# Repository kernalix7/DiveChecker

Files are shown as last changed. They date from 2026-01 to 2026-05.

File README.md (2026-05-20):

<div align="center">

DiveChecker

### See your equalization.

<p>Real-time pressure visualization for freediving equalization training — 100Hz BMP280 sensor,<br>
USB MIDI zero latency, six-platform Flutter app, ECDSA-authenticated RP2350 firmware.<br>
Two products: <strong>DiveChecker</strong> (sensor) and <strong>DiveChecker Vent</strong> (dry-land Mouthfill trainer).</p>

<pre><code># Get the app
Android: https://play.google.com/store/apps/details?id=kr.createch.divechecker
iOS:     https://apps.apple.com/kr/app/divechecker/id6758508799
Desktop: https://github.com/kernalix7/DiveChecker/releases/latest

# Buy the device
https://smartstore.naver.com/createch/products/13224634919</code></pre>

<a href="website/assets/images/hero-product.jpg">
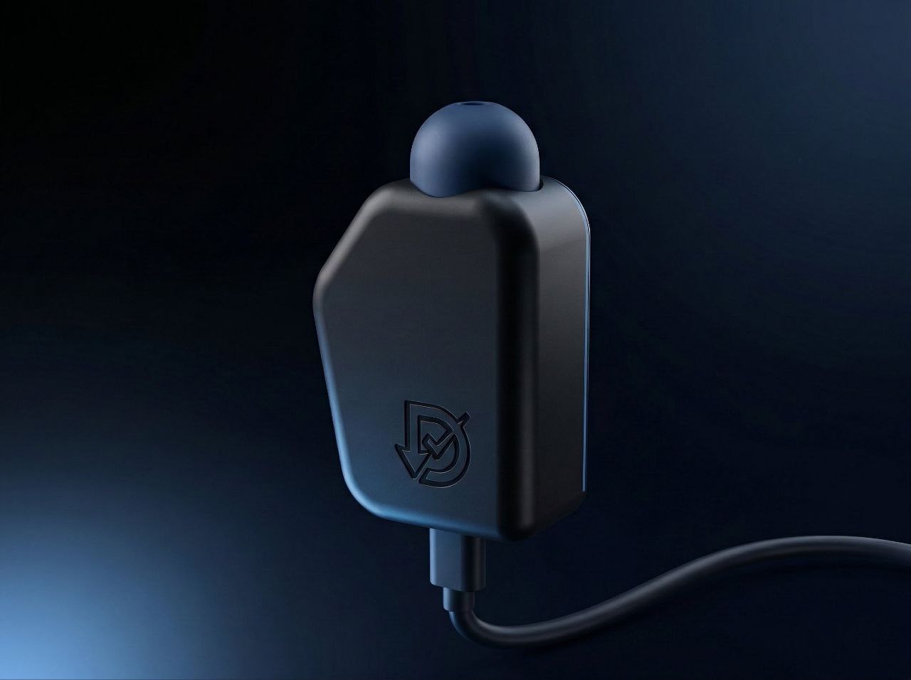
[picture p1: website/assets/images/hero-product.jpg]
DiveChecker DC-EQ01 — freediving equalization sensor
  
</a>

<sub>DiveChecker DC-EQ01 — measures nasal pressure at 100Hz, visualizes Frenzel/Valsalva/Mouthfill curves in real time.</sub>














###### Runs on








<sub>**English** &nbsp;·&nbsp; [한국어](docs/README.ko.md) &nbsp;·&nbsp; [Site](https://divechecker.createch.kr) &nbsp;·&nbsp; [Vent (Mouthfill)](https://divechecker.createch.kr/vent.html) &nbsp;·&nbsp; [Features](#-features) &nbsp;·&nbsp; [Quick Start](#-quick-start) &nbsp;·&nbsp; [Architecture](#-architecture)</sub>

</div>

---

> ### Status
> DiveChecker DC-EQ01 (sensor) is **shipping** (App v8.6.0, Firmware v6.0.0, KC-certified). DiveChecker Vent (Mouthfill dry-land trainer) is **coming soon** — sign up at the [marketing site](https://divechecker.createch.kr/vent.html). Report issues at <https://github.com/kernalix7/DiveChecker/issues>.

---

## 🎯 Overview

DiveChecker is a professional monitoring system that helps freedivers effectively practice **equalization (ear pressure equalization)** training.

Using a pressure sensor connected to a mouthpiece, it precisely measures subtle pressure changes (300-1250 hPa sensor range) when blowing or sucking through the mouth with **100Hz internal sampling + configurable output rate (4-50Hz)**, and visualizes them in real-time graphs.

### Architecture (v8.0.0)

**Smart MCU + Intelligent App**

```
[BMP280] → 100Hz → [MCU] → USB MIDI → [Flutter App]
    │                   │                       │
        └── Raw sensor      └── IIR + Averaging    └── All logic:
            data               Firmware filtering      - Display
                               Output: 4-50Hz          - Analysis
                                                       - Storage
```

| Component | Role |
|---|---|
| **MCU** | Sensor reading + IIR/Averaging filter + Configurable output rate |
| **App** | Display, analysis, storage (flexible, OTA updatable) |

### Supported Hardware

| MCU | Sensor | Status |
|-----|---|---|
| **Pico RP2350** | BMP280 | ✅ Fully supported |

### Why DiveChecker?

| Problem | DiveChecker Solution |
|---|---|
| Cannot verify if equalization is correct | Instant feedback with real-time pressure graphs |
| Difficult to measure training effectiveness | Objective evaluation with session recording + peak analysis |
| Difficult to practice consistent technique | Advanced analysis with rhythm score, fatigue index, etc. |

---

## ✨ Features

### 📊 Real-time Pressure Monitoring

<table>
<tr>
<td width="50%">

**Sensor Specs**
- **Sampling**: 100Hz internal → 4-50Hz output (configurable)
- **Firmware Filtering**: IIR x2 + Averaging
- **Latency**: ~10ms (sensor to app)
- **Sensor Range**: 300-1250 hPa (BMP280 extended)
- **Resolution**: 0.001 hPa (0.0016 hPa sensor resolution)

</td>
<td width="50%">

**Visualization**
- Real-time line chart (fl_chart)
- Pinch zoom / drag pan gestures
- 30-second sliding window
- Dynamic Y-axis auto-scaling
- Curved chart with smooth bezier
- Max/Avg pressure real-time display

</td>
</tr>
</table>

### 🔬 Advanced Peak Analysis

Detailed equalization quality analysis after measurement:

| Metric | Description |
|---|---|
| **Rhythm Score** | Peak interval consistency (CV-based) |
| **Pressure Score** | Peak intensity uniformity |
| **Technique Score** | Rise/fall time, peak width analysis |
| **Fatigue Index** | Pressure decrease trend during session |
| **Overall Grade** | S~F grade overall evaluation |

**Peak Classification**: Weak / Moderate / Strong intensity classification

### 💾 Data Management

- **SQLite / IndexedDB**: Platform-specific auto-selection (Native/Web)
- **Session Recording**: Date, time, max/avg pressure, sample rate, notes
- **Graph Notes**: Add notes at specific points (numbered markers)
- **Backup/Restore**: JSON-based data export/import
- **Cursor Indicator**: Touch position with time/pressure display

### 🌐 Multi-language Support

- 🇺🇸 English
- 🇰🇷 Korean (한국어)
- 🇯🇵 Japanese (日本語)
- 🇨🇳 Simplified Chinese (简体中文)
- 🇹🇼 Traditional Chinese (繁體中文)

### ⚙️ Calibration & Configuration

- **Atmospheric Calibration**: 3-second sample collection then baseline setting
- **Output Rate Control**: 4-50Hz via F command
- **Oversampling Adjustment**: 1x ~ 16x (MCU command)

---

## 🔐 Security & Reliability

### Device Authentication (ECDSA P-256)

| Feature | Description |
|---|---|
| **Challenge-Response** | 32-byte random nonce + ECDSA signature verification |
| **Private Key Storage** | OTP (One-Time Programmable) memory — non-extractable |
| **Constant-Time Comparison** | Timing attack prevention |
| **Memory Zeroing** | `mbedtls_platform_zeroize()` after crypto operations |

### PIN Protection

| Feature | Description |
|---|---|
| **Rate Limiting** | Exponential backoff (1s → 2s → ... → 60s max) |
| **Persistent Lockout** | PIN failure count survives reboot (Flash stored) |
| **Constant-Time PIN Verify** | No timing side-channel |

### Data Integrity

| Feature | Description |
|---|---|
| **Flash CRC32** | Settings integrity check on load |
| **Legacy Migration** | Old settings (no CRC) auto-upgraded on save |
| **Wear Leveling** | 16-slot rotation in 4KB sector |
| **3s Write Debounce** | Prevents flash wear from rapid slider changes |

### Self-Recovery Mechanisms

| Mechanism | Trigger | Recovery Action |
|---|---|---|
| **Watchdog** | 8s boot / 2s operational | Auto reboot |
| **Sensor Auto-Retry** | I2C failure | 5-second periodic retry (Core 1) |
| **App Auto-Reconnect** | USB disconnect | Exponential backoff (2/4/6s, 3 attempts) |
| **SysEx Parser Timeout** | Incomplete message | 500ms → reset to IDLE |
| **PIO Fallback** | PIO0 unavailable | Automatically use PIO1 |
| **Over-range Recovery** | Sensor saturation | Discard 30 samples after reset |

### Stability Features

| Feature | Description |
|---|---|
| **Dual-Core Isolation** | Core 0: USB/MIDI, Core 1: Sensor (100Hz) |
| **I2C Mutex Protection** | Cross-core access serialization |
| **FIFO Communication** | Lock-free inter-core message passing |
| **Saturating Counters** | Diagnostics counters never overflow |
| **Atomic Config Updates** | Output rate changes via volatile + barrier |

---

## 📱 Screens

| Screen | Description |
|---|---|
| 🏠 **Home** | Device connection, real-time pressure display, calibration |
|| 📺 **Monitor** | Real-time streaming chart with dynamic Y-axis |
|| 📈 **Measurement** | Live graph, Start/Stop/Pause, session recording |
| 📋 **History** | Session list → Graph detail → Peak analysis |
| ⚙️ **Settings** | Language, backup/restore, device settings, firmware update |

---

## 🚀 Quick Start

### Prerequisites

| Component | Version | Notes |
|---|---|---|
| Flutter SDK | 3.10.4+ | `flutter --version` |
| Pico SDK | Latest | For RP2350 firmware |
| USB Cable | - | Data transfer capable cable |

### 1. Install and Run App

```bash
git clone https://github.com/kernalix7/divechecker.git
cd divechecker/_0_DiveChecker-APP

flutter pub get
flutter gen-l10n
flutter run -d linux    # or android, windows, macos
```

### 2. Upload Firmware

```bash
# Build with Pico SDK
cd 0_Pico2-Firmware/Divechecker
mkdir build && cd build
cmake .. && make
# Copy .uf2 to Pico in BOOTSEL mode
```

### 3. Connect and Measure

1. Connect MCU to PC/Android via USB
2. App Home → **CONNECT DEVICE**
3. Select device → Connection complete
4. **Calibrate** (sensor stabilization)
5. Measurement tab → **START**

---

## 🏗️ Architecture

```
00_Divechecker/
│
├── 📱 _0_DiveChecker-APP/          # Flutter cross-platform app
│   ├── lib/
│   │   ├── main.dart               # App entry point
│   │   ├── constants/              # Theme, colors, app config
│   │   ├── core/                   # DB interface
│   │   ├── l10n/                   # Localization (EN/KO/JA/ZH/ZH_TW)
│   │   ├── models/                 # PressureData, GraphNote
│   │   ├── providers/              # State management (Provider)
│   │   │   ├── midi_provider.dart        # USB MIDI connection
│   │   │   ├── measurement_controller.dart # Measurement logic
│   │   │   └── session_repository.dart   # Session cache
│   │   ├── screens/
│   │   │   ├── home_screen.dart            # Connection & status
│   │   │   ├── monitor_screen.dart         # Real-time streaming
│   │   │   ├── measurement_screen.dart     # Real-time measurement
│   │   │   ├── history_screen.dart         # Session list
│   │   │   ├── graph_detail_page.dart      # Detailed graph + cursor
│   │   │   ├── peak_analysis_page.dart     # Peak analysis
│   │   │   ├── device_selection_screen.dart # Device selection
│   │   │   ├── device_settings_screen.dart # Device config
│   │   │   └── firmware_update_screen.dart # OTA update
│   │   ├── services/
│   │   │   ├── unified_database_service.dart  # DB integration
│   │   │   └── backup_service.dart            # Backup/restore
│   │   ├── security/
│   │   │   └── device_authenticator.dart      # ECDSA authentication
│   │   ├── utils/
│   │   │   └── peak_analyzer.dart        # Peak analysis algorithms
│   │   └── widgets/                # UI components
│   └── pubspec.yaml
│
├── 🔧 0_Pico2-Firmware/            # Pico RP2350 project
│   └── Divechecker/
│       ├── Divechecker.c           # Main firmware (dual-core, ~1800 lines)
│       ├── midi_sysex.c/h          # USB MIDI SysEx protocol
│       ├── usb_descriptors.c       # TinyUSB device descriptors
│       ├── ws2812.pio              # WS2812 LED PIO program
│       └── CMakeLists.txt          # Build config (Pico SDK 2.2.0)
│
├── 📐 0_CAD/                       # Hardware design (FreeCAD)
│
└── 📜 LICENSE                      # Apache 2.0 + CERN-OHL-S v2
```

### Communication Protocol (USB MIDI SysEx)

SysEx format: `F0 7D 01 [cmd] [data...] F7`
- Manufacturer ID: `0x7D` (educational/development)
- Device ID: `0x01` (DiveChecker)

**Device → App**

| Command | Hex | Description |
|---|-----|---|
| Pressure | 0x01 | Delta pressure (7-bit encoded int32, hPa×1000) |
| Device Info | 0x02 | Serial, name, FW version, sensor status |
| Config | 0x03 | Output rate response |
| Auth Response | 0x04 | ECDSA signature (nibble-encoded) |
| Over-range Alert | 0x06 | Sensor exceeded measurement range |
| Temperature | 0x07 | BMP280 temperature (int16×100) |
| Diagnostics | 0x08 | Uptime, error counts, I2C recovery |
| Full Config | 0x09 | All configurable parameters |
| ACK | 0x0A | Command acknowledgment (cmd + status) |
| Ping | 0x10 | Keepalive request |
| Pong | 0x11 | Keepalive response |

**App → Device**

| Command | Hex | Description |
|---|-----|---|
| Ping | 0x10 | Connection keepalive |
| Request Info | 0x20 | Request device info |
| Set Name | 0x21 | Set device name (PIN required) |
| Set Output Rate | 0x22 | Set output rate (4-50 Hz) |
| Reset Baseline | 0x23 | Reset pressure baseline |
| Get Config | 0x24 | Request full config dump |
| Set LED | 0x25 | Set LED brightness (0-100) |
| Reset Sensor | 0x26 | Manual sensor re-init |
| Factory Reset | 0x27 | Factory reset (PIN required) |
| Set Noise Floor | 0x28 | Set noise threshold (0-50) |
| Get Temperature | 0x29 | Request temperature |
| Enter Bootloader | 0x2A | Enter BOOTSEL mode (PIN required) |
| Get Diagnostics | 0x2B | Request runtime diagnostics |
| Set Oversampling | 0x2C | Set pressure oversampling (0-5) |
| Set IIR Filter | 0x2D | Set IIR filter coefficient (0-4) |
| Soft Reboot | 0x2E | Soft reboot (PIN required) |
| Auth Challenge | 0x30 | ECDSA auth (32-byte nonce) |
| Set PIN | 0x31 | Change PIN (old PIN + new PIN) |

---

## 🔧 Hardware

### Supported MCU

| MCU | Sensor | Status | Notes |
|-----|---|---|---|
| **Pico RP2350** | BMP280 | ✅ Supported | Dual-core, USB MIDI, ECDSA auth |

### Circuit Configuration

**Pico RP2350 + BMP280:**
```
Pico RP2350         BMP280 (I2C)
────────────        ────────────
3.3V         ────── VCC
GND          ────── GND
GP8 (SDA)    ────── SDA
GP9 (SCL)    ────── SCL
GP16         ────── WS2812 LED
```

### Sensor Requirements

- **Pressure Sensor**: BMP280
- **Sensitivity**: ±0.01 hPa or better recommended
- **Mouthpiece Connection**: Connect to sensor via tube

> 📌 See [0_Pico2-Firmware/Divechecker/README.md](0_Pico2-Firmware/Divechecker/README.md) for detailed setup

---

## 🔮 Roadmap

### ✅ v1.0.0 Completed
- [x] 🎯 **Real-time pressure monitoring** - 100Hz internal + configurable output
- [x] 📊 **Peak analysis** - Rhythm, pressure, technique scores
- [x] 💾 **Session management** - Record, review, notes
- [x] 🌐 **Multi-language** - English, Korean, Japanese, Chinese (Simplified/Traditional)
- [x] 🔧 **Device settings** - Output rate, oversampling control
- [x] 🔄 **Firmware update** - OTA update support
- [x] 🔐 **Authentication** - ECDSA device authentication

### 🔜 Next Goals
- [ ] ⏸️ **Monitor pause & range save** - Pause monitoring and save specific ranges
- [ ] 🫁 **Lung capacity measurement** - Max inhale/exhale volume check
- [ ] 🧘 **CO₂ table trainer** - Carbon dioxide tolerance training
- [ ] 💨 **O₂ table trainer** - Hypoxia adaptation training
- [ ] 📤 **CSV export** - External analysis tool integration
- [ ] 🌐 **Cloud sync** - Firebase-based backup
- [ ] 🎯 **Training programs** - Guided sessions (8-week course, etc.)

---

## 🤝 Contributing

Contributions are welcome!

```bash
# After forking
git clone https://github.com/YOUR_USERNAME/divechecker.git
cd divechecker/_0_DiveChecker-APP
flutter pub get
flutter run
```

See [CONTRIBUTING.md](CONTRIBUTING.md) for details.

---

## 📄 License

This project is dual-licensed:

| Component | License | Scope |
|---|---|---|
| **Software** | [Apache License 2.0](https://www.apache.org/licenses/LICENSE-2.0) | App, firmware code |
| **Hardware** | [CERN-OHL-S v2](https://ohwr.org/cern_ohl_s_v2.txt) | Circuits, CAD designs |

See the [LICENSE](LICENSE) file for details.

---

## ⭐ Star History

<a href="https://star-history.com/#kernalix7/DiveChecker&Date">
  <picture>
    <source media="(prefers-color-scheme: dark)" srcset="https://api.star-history.com/svg?repos=kernalix7/DiveChecker&type=Date&theme=dark" />
    <source media="(prefers-color-scheme: light)" srcset="https://api.star-history.com/svg?repos=kernalix7/DiveChecker&type=Date" />
    Star History Chart
  </picture>
</a>

## 💖 Sponsor

DiveChecker is built and maintained by [@kernalix7](https://github.com/kernalix7) as a one-person hardware+app+firmware+site stack. If it helps your training (or your dive shop, your students, your PB), a tip keeps the lights on for the next firmware build, the next translation pass, the next CAD revision.





Ko-fi handles international cards and PayPal; fairy.hada.io is a Korean tipping platform; the GitHub Sponsor button (repo header) wires both. Bug reports, PRs, and stars on the repo are equally appreciated and free.

See [`.github/FUNDING.yml`](.github/FUNDING.yml) for the configuration.

---

<div align="center">

**Made with ❤️ for the Freediving Community**

[⬆ Back to Top](#-divechecker)

</div>

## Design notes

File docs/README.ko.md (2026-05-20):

<div align="center">

DiveChecker

### 이퀄라이징을 눈으로 봅니다.

<p>프리다이빙 이퀄라이징 훈련용 실시간 압력 시각화 — 100Hz BMP280 센서,<br>
USB MIDI 제로 레이턴시, 6개 플랫폼 Flutter 앱, ECDSA 인증 RP2350 펌웨어.<br>
두 가지 제품: <strong>DiveChecker</strong> (센서) + <strong>DiveChecker Vent</strong> (지상 마우스필 트레이너).</p>

<pre><code># 앱 받기
Android: https://play.google.com/store/apps/details?id=kr.createch.divechecker
iOS:     https://apps.apple.com/kr/app/divechecker/id6758508799
데스크탑: https://github.com/kernalix7/DiveChecker/releases/latest

# 디바이스 구매
https://smartstore.naver.com/createch/products/13224634919</code></pre>

<a href="../website/assets/images/hero-product.jpg">
  DiveChecker DC-EQ01 — 프리다이빙 이퀄라이징 센서
</a>

<sub>DiveChecker DC-EQ01 — 코쪽 압력을 100Hz로 측정하고 프렌젤·발살바·마우스필 곡선을 실시간으로 시각화합니다.</sub>




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

###### 동작 플랫폼








<sub>[English](../README.md) &nbsp;·&nbsp; **한국어** &nbsp;·&nbsp; [사이트](https://divechecker.createch.kr) &nbsp;·&nbsp; [Vent (마우스필)](https://divechecker.createch.kr/vent.html) &nbsp;·&nbsp; [기능](#-기능) &nbsp;·&nbsp; [빠른 시작](#-빠른-시작) &nbsp;·&nbsp; [아키텍처](#-아키텍처)</sub>

</div>

---

> ### Status
> DiveChecker DC-EQ01 (센서)는 **출시 완료** (앱 v8.6.0, 펌웨어 v6.0.0, KC 인증). DiveChecker Vent (마우스필 지상 트레이너)는 **곧 출시** — [마케팅 사이트](https://divechecker.createch.kr/vent.html)에서 출시 알림 신청. 이슈는 <https://github.com/kernalix7/DiveChecker/issues>에 제보.

---

## 🎯 개요

DiveChecker는 프리다이버들이 **이퀄라이징(귀 압력 평형)** 훈련을 효과적으로 수행할 수 있도록 도와주는 전문 모니터링 시스템입니다.

마우스피스에 연결된 압력 센서를 통해 입으로 불거나 빨 때의 미세한 압력 변화(300-1250 hPa 센서 범위)를 **100Hz 내부 샘플링 + 설정 가능한 출력 속도(4-50Hz)**로 정밀하게 측정하고, 실시간 그래프로 시각화합니다.

### 아키텍처 (v8.0.0)

**스마트 MCU + 지능형 앱**

```
[BMP280] → 100Hz → [MCU] → USB MIDI → [Flutter 앱]
    │                   │                      │
        └── 원본 센서       └── IIR + 평균화       └── 모든 로직:
            데이터             펌웨어 필터링            - 표시
                               출력: 4-50Hz            - 분석
                                                       - 저장
```

| 구성요소 | 역할 |
|---|---|
| **MCU** | 센서 읽기 + IIR/평균화 필터 + 설정 가능한 출력 속도 |
| **앱** | 표시, 분석, 저장 (유연, OTA 업데이트 가능) |

### 지원 하드웨어

| MCU | 센서 | 상태 |
|-----|---|---|
| **Pico RP2350** | BMP280 | ✅ 완전 지원 |

### 왜 DiveChecker인가?

| 문제점 | DiveChecker 솔루션 |
|---|---|
| 이퀄라이징이 제대로 되는지 확인 불가 | 실시간 압력 그래프로 즉각적 피드백 |
| 훈련 효과 측정 어려움 | 세션 기록 + 피크 분석으로 객관적 평가 |
| 일관성 있는 기술 연습 어려움 | 리듬 점수, 피로도 지수 등 고급 분석 |

---

## ✨ 기능

### 📊 실시간 압력 모니터링

<table>
<tr>
<td width="50%">

**센서 스펙**
- **샘플링**: 100Hz 내부 → 4-50Hz 출력 (설정 가능)
- **펌웨어 필터링**: IIR x2 + 평균화
- **지연 시간**: ~10ms (센서 → 앱)
- **센서 범위**: 300-1250 hPa (BMP280 확장)
- **분해능**: 0.001 hPa (센서 0.0016 hPa)

</td>
<td width="50%">

**시각화**
- 실시간 라인 차트 (fl_chart)
- 핀치 줌 / 드래그 팬 제스처
- 30초 슬라이딩 윈도우
- 동적 Y축 자동 스케일링
- 부드러운 베지어 곡선 차트
- 최대/평균 압력 실시간 표시

</td>
</tr>
</table>

### 🔬 고급 피크 분석

측정 완료 후 상세한 이퀄라이징 품질 분석:

| 지표 | 설명 |
|---|---|
| **리듬 점수** | 피크 간격의 일관성 (CV 기반) |
| **압력 점수** | 피크 강도의 균일성 |
| **테크닉 점수** | 상승/하강 시간, 피크 폭 분석 |
| **피로도 지수** | 세션 중 압력 감소 추세 |
| **종합 등급** | S~F 등급으로 전체 평가 |

**피크 분류**: Weak / Moderate / Strong 강도별 분류

### 💾 데이터 관리

- **SQLite / IndexedDB**: 플랫폼별 자동 선택 (Native/Web)
- **세션 기록**: 날짜, 시간, 최대/평균 압력, 샘플 레이트, 메모
- **그래프 노트**: 특정 시점에 메모 추가 (번호 마커)
- **백업/복원**: JSON 기반 데이터 내보내기/가져오기
- **커서 인디케이터**: 터치 위치에 시간/압력 표시

### 🌐 다국어 지원

- 🇺🇸 English
- 🇰🇷 한국어
- 🇯🇵 日本語
- 🇨🇳 简体中文
- 🇹🇼 繁體中文

### ⚙️ 캘리브레이션 및 설정

- **대기압 캘리브레이션**: 3초간 샘플 수집 후 기준점 설정
- **출력 속도 조절**: F 명령으로 4-50Hz 설정
- **오버샘플링 조절**: 1x ~ 16x (MCU 명령)

---

## 🔐 보안 및 안정성

### 장치 인증 (ECDSA P-256)

| 기능 | 설명 |
|---|---|
| **챌린지-응답** | 32바이트 랜덤 논스 + ECDSA 서명 검증 |
| **개인키 저장** | OTP (One-Time Programmable) 메모리 — 추출 불가 |
| **상수 시간 비교** | 타이밍 공격 방지 |
| **메모리 제로화** | 암호화 작업 후 `mbedtls_platform_zeroize()` |

### PIN 보호

| 기능 | 설명 |
|---|---|
| **Rate Limiting** | 지수 백오프 (1초 → 2초 → ... → 최대 60초) |
| **영구 잠금** | PIN 실패 횟수 재부팅 후에도 유지 (Flash 저장) |
| **상수 시간 PIN 검증** | 타이밍 사이드채널 없음 |

### 데이터 무결성

| 기능 | 설명 |
|---|---|
| **Flash CRC32** | 로드 시 설정 무결성 검사 |
| **레거시 마이그레이션** | 이전 설정(CRC 없음) 저장 시 자동 업그레이드 |
| **마모 평준화** | 4KB 섹터 내 16슬롯 로테이션 |
| **3초 쓰기 디바운스** | 빠른 슬라이더 조작 시 Flash 마모 방지 |

### 자가복구 메커니즘

| 메커니즘 | 트리거 | 복구 동작 |
|---|---|---|
| **워치독** | 부팅 8초 / 운영 2초 | 자동 재부팅 |
| **센서 자동 재시도** | I2C 실패 | 5초마다 재시도 (Core 1) |
| **앱 자동 재연결** | USB 끊김 | 지수 백오프 (2/4/6초, 3회) |
| **SysEx 파서 타임아웃** | 불완전 메시지 | 500ms → IDLE 리셋 |
| **PIO 폴백** | PIO0 사용 불가 | 자동으로 PIO1 사용 |
| **과범위 복구** | 센서 포화 | 리셋 후 30샘플 폐기 |

### 안정성 기능

| 기능 | 설명 |
|---|---|
| **듀얼코어 분리** | Core 0: USB/MIDI, Core 1: 센서 (100Hz) |
| **I2C 뮤텍스 보호** | 크로스코어 접근 직렬화 |
| **FIFO 통신** | 락프리 코어간 메시지 전달 |
| **포화 카운터** | 진단 카운터 오버플로우 방지 |
| **원자적 설정 업데이트** | volatile + 메모리 배리어로 출력 속도 변경 |

---

## 📱 화면 구성

| 화면 | 설명 |
|---|---|
| 🏠 **홈** | 장치 연결, 실시간 압력 표시, 캘리브레이션 |
|| 📺 **모니터** | 동적 Y축 실시간 스트리밍 차트 |
|| 📈 **측정** | 실시간 그래프, 시작/정지/일시정지, 세션 저장 |
| 📋 **기록** | 세션 목록 → 상세 그래프 → 피크 분석 |
| ⚙️ **설정** | 언어, 백업/복원, 장치 설정, 펌웨어 업데이트 |

---

## 🚀 빠른 시작

### 사전 요구사항

| 구성요소 | 버전 | 비고 |
|---|---|---|
| Flutter SDK | 3.10.4+ | `flutter --version` |
| Pico SDK | 최신 | RP2350 펌웨어용 |
| USB 케이블 | - | 데이터 전송 지원 케이블 |

### 1. 앱 설치 및 실행

```bash
git clone https://github.com/kernalix7/divechecker.git
cd divechecker/_0_DiveChecker-APP

flutter pub get
flutter gen-l10n
flutter run -d linux    # 또는 android, windows, macos
```

### 2. 펌웨어 업로드

```bash
# Pico SDK로 빌드
cd 0_Pico2-Firmware/Divechecker
mkdir build && cd build
cmake .. && make
# BOOTSEL 모드에서 .uf2 파일을 Pico에 복사
```

### 3. 연결 및 측정

1. MCU를 USB로 PC/Android에 연결
2. 앱 홈 → **장치 연결**
3. 장치 선택 → 연결 완료
4. **캘리브레이션** (센서 안정화)
5. 측정 탭 → **시작**

---

## 🏗️ 아키텍처

```
00_Divechecker/
│
├── 📱 _0_DiveChecker-APP/          # Flutter 크로스플랫폼 앱
│   ├── lib/
│   │   ├── main.dart               # 앱 진입점
│   │   ├── constants/              # 테마, 색상, 앱 설정
│   │   ├── core/                   # DB 인터페이스
│   │   ├── l10n/                   # 다국어 (EN/KO/JA/ZH/ZH_TW)
│   │   ├── models/                 # PressureData, GraphNote
│   │   ├── providers/              # 상태관리 (Provider)
│   │   ├── screens/                # 화면 (장치 설정, 펌웨어 업데이트 포함)
│   │   ├── services/               # DB, 백업, 업데이트 서비스
│   │   ├── utils/                  # 피크 분석 알고리즘
│   │   └── widgets/                # UI 컴포넌트
│   └── pubspec.yaml
│
├── 🔧 0_Pico2-Firmware/            # Pico RP2350 프로젝트
│   └── Divechecker/
│       ├── Divechecker.c           # 메인 펌웨어 (듀얼코어, ~1800줄)
│       ├── midi_sysex.c/h          # USB MIDI SysEx 프로토콜
│       ├── usb_descriptors.c       # TinyUSB 디바이스 디스크립터
│       ├── ws2812.pio              # WS2812 LED PIO 프로그램
│       └── CMakeLists.txt          # 빌드 설정 (Pico SDK 2.2.0)
│
├── 📐 0_CAD/                       # 하드웨어 설계 (FreeCAD)
│
└── 📜 LICENSE                      # Apache 2.0 + CERN-OHL-S v2
```

### 통신 프로토콜 (USB MIDI SysEx)

SysEx 형식: `F0 7D 01 [cmd] [data...] F7`
- 제조사 ID: `0x7D` (교육/개발용)
- 기기 ID: `0x01` (DiveChecker)

**기기 → 앱**

| 명령 | Hex | 설명 |
|---|-----|---|
| Pressure | 0x01 | 차압 (7비트 인코딩 int32, hPa×1000) |
| Device Info | 0x02 | 시리얼, 이름, FW 버전, 센서 상태 |
| Config | 0x03 | 출력 속도 응답 |
| Auth Response | 0x04 | ECDSA 서명 (니블 인코딩) |
| Over-range Alert | 0x06 | 센서 측정 범위 초과 |
| Temperature | 0x07 | BMP280 온도 (int16×100) |
| Diagnostics | 0x08 | 가동시간, 에러 카운트, I2C 복구 |
| Full Config | 0x09 | 모든 설정 파라미터 |
| ACK | 0x0A | 명령 확인 (cmd + 상태) |
| Ping | 0x10 | 킵얼라이브 요청 |
| Pong | 0x11 | 킵얼라이브 응답 |

**앱 → 기기**

| 명령 | Hex | 설명 |
|---|-----|---|
| Ping | 0x10 | 연결 유지 |
| Request Info | 0x20 | 기기 정보 요청 |
| Set Name | 0x21 | 기기 이름 설정 (PIN 필요) |
| Set Output Rate | 0x22 | 출력 속도 설정 (4-50 Hz) |
| Reset Baseline | 0x23 | 압력 기준점 리셋 |
| Get Config | 0x24 | 전체 설정 덤프 요청 |
| Set LED | 0x25 | LED 밝기 설정 (0-100) |
| Reset Sensor | 0x26 | 수동 센서 재초기화 |
| Factory Reset | 0x27 | 공장 초기화 (PIN 필요) |
| Set Noise Floor | 0x28 | 노이즈 임계값 설정 (0-50) |
| Get Temperature | 0x29 | 온도 요청 |
| Enter Bootloader | 0x2A | BOOTSEL 모드 진입 (PIN 필요) |
| Get Diagnostics | 0x2B | 런타임 진단 요청 |
| Set Oversampling | 0x2C | 압력 오버샘플링 설정 (0-5) |
| Set IIR Filter | 0x2D | IIR 필터 계수 설정 (0-4) |
| Soft Reboot | 0x2E | 소프트 재부팅 (PIN 필요) |
| Auth Challenge | 0x30 | ECDSA 인증 (32바이트 논스) |
| Set PIN | 0x31 | PIN 변경 (기존 PIN + 새 PIN) |

---

## 🔧 하드웨어

### 지원 MCU

| MCU | 센서 | 상태 | 비고 |
|-----|---|---|---|
| **Pico RP2350** | BMP280 | ✅ 지원 | 듀얼코어, USB MIDI, ECDSA 인증 |

### 회로 구성

**Pico RP2350 + BMP280:**
```
Pico RP2350         BMP280 (I2C)
────────────        ────────────
3.3V         ────── VCC
GND          ────── GND
GP8 (SDA)    ────── SDA
GP9 (SCL)    ────── SCL
GP16         ────── WS2812 LED
```

### 센서 요구사항

- **압력 센서**: BMP280
- **감도**: ±0.01 hPa 이상 권장
- **마우스피스 연결**: 튜브로 센서와 연결

> 📌 상세 설정은 [0_Pico2-Firmware/Divechecker/README.md](../0_Pico2-Firmware/Divechecker/README.md) 참조

---

## 🔮 로드맵

### ✅ v1.0.0 완료
- [x] 🎯 **실시간 압력 모니터링** - 100Hz 내부 + 설정 가능 출력
- [x] 📊 **피크 분석** - 리듬, 압력, 테크닉 점수
- [x] 💾 **세션 관리** - 기록, 조회, 메모
- [x] 🌐 **다국어** - 영어, 한국어, 일본어, 중국어 (간체/번체)
- [x] 🔧 **장치 설정** - 출력 속도, 오버샘플링 제어
- [x] 🔄 **펌웨어 업데이트** - OTA 업데이트 지원
- [x] 🔐 **인증** - ECDSA 기기 인증

### 🔜 다음 목표
- [ ] ⏸️ **모니터 일시정지 & 범위 저장** - 모니터링 일시정지 및 특정 범위 저장
- [ ] 🫁 **폐활량 측정** - 최대 흡기/호기 용량 체크
- [ ] 🧘 **CO₂ 테이블 트레이너** - 이산화탄소 내성 훈련
- [ ] 💨 **O₂ 테이블 트레이너** - 저산소 적응 훈련
- [ ] 📤 **CSV 내보내기** - 외부 분석 도구 연동
- [ ] 🌐 **클라우드 동기화** - Firebase 기반 백업
- [ ] 🎯 **훈련 프로그램** - 가이드 세션 (8주 코스 등)

---

## 🤝 기여하기

기여를 환영합니다!

```bash
# Fork 후
git clone https://github.com/YOUR_USERNAME/divechecker.git
cd divechecker/_0_DiveChecker-APP
flutter pub get
flutter run
```

자세한 내용은 [CONTRIBUTING.md](../CONTRIBUTING.md)를 참조하세요.

---

## 📄 라이선스

이 프로젝트는 이중 라이선스로 제공됩니다:

| 구성요소 | 라이선스 | 범위 |
|---|---|---|
| **소프트웨어** | [Apache License 2.0](https://www.apache.org/licenses/LICENSE-2.0) | 앱, 펌웨어 코드 |
| **하드웨어** | [CERN-OHL-S v2](https://ohwr.org/cern_ohl_s_v2.txt) | 회로, CAD 설계 |

자세한 내용은 [LICENSE](../LICENSE) 파일을 참조하세요.

---

## ⭐ Star History

<a href="https://star-history.com/#kernalix7/DiveChecker&Date">
  <picture>
    <source media="(prefers-color-scheme: dark)" srcset="https://api.star-history.com/svg?repos=kernalix7/DiveChecker&type=Date&theme=dark" />
    <source media="(prefers-color-scheme: light)" srcset="https://api.star-history.com/svg?repos=kernalix7/DiveChecker&type=Date" />
    Star History Chart
  </picture>
</a>

## 💖 후원

DiveChecker는 [@kernalix7](https://github.com/kernalix7) 1인이 하드웨어 + 앱 + 펌웨어 + 사이트까지 통째로 만들고 유지하는 프로젝트입니다. 훈련(또는 다이브샵, 학생, PB)에 도움이 되셨다면, 작은 후원이 다음 펌웨어 빌드 / 번역 / CAD 개정의 동력이 됩니다.





Ko-fi는 해외 카드 / PayPal 결제, fairy.hada.io는 한국 후원 플랫폼, GitHub Sponsor 버튼(저장소 상단)은 두 곳을 함께 연결합니다. 버그 제보, PR, 저장소 별표도 모두 동등하게 감사하며 무료입니다.

설정은 [`.github/FUNDING.yml`](../.github/FUNDING.yml) 참조.

---

<div align="center">

**Made with ❤️ for the Freediving Community**

[⬆ 맨 위로](#-divechecker)

</div>

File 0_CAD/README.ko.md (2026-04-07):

# DiveChecker 하드웨어 설계

프리다이빙 이퀄라이징 압력 측정기의 하드웨어 설계 파일입니다.

## 파일 목록

| 파일 | 설명 |
|---|---|
| `Device_V4.FCStd` | 본체 케이스 설계 v4 (FreeCAD) |
| `BME280-5V.FCStd` | BME280 센서 모듈 케이스 (FreeCAD) |

> **참고**: `.legacy-files/` 폴더에는 이전 버전의 설계 파일들이 보관되어 있습니다.

## 소프트웨어 요구사항

- [FreeCAD](https://www.freecad.org/) 0.21+ 권장

## 출력 가이드

### 권장 설정 (FDM)

| 설정 | 값 |
|---|---|
| 레이어 높이 | 0.2mm |
| 인필 | 20% |
| 서포트 | 필요시 |
| 재질 | PLA / PETG |

## 라이선스

Copyright (C) 2025-2026 Createch (legal@createch.kr)

이 하드웨어 설계는 [CERN-OHL-S v2](https://ohwr.org/cern_ohl_s_v2.txt) 라이선스로 제공됩니다.

자세한 내용은 프로젝트 루트의 [LICENSE](../LICENSE) 파일을 참조하세요.

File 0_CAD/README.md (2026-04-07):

# DiveChecker Hardware Designs

Hardware design files for freediving equalization pressure monitor.

[🇰🇷 한국어](README.ko.md)

## File List

| File | Description |
|---|---|
| `Device_V4.FCStd` | Main case design v4 (FreeCAD) |
| `BME280-5V.FCStd` | BME280 sensor module case (FreeCAD) |

> **Note**: `.legacy-files/` folder contains previous version design files.

## Software Requirements

- [FreeCAD](https://www.freecad.org/) 0.21+ recommended

## Printing Guide

### Recommended Settings (FDM)

| Setting | Value |
|---|---|
| Layer Height | 0.2mm |
| Infill | 20% |
| Support | If needed |
| Material | PLA / PETG |

## License

Copyright (C) 2025-2026 Createch (legal@createch.kr)

These hardware designs are licensed under [CERN-OHL-S v2](https://ohwr.org/cern_ohl_s_v2.txt).

See the project root [LICENSE](../LICENSE) file for details.

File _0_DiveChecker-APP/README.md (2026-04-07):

# DiveChecker Flutter App

Cross-platform pressure monitoring app for freediving equalization training.

[🇰🇷 한국어](README.ko.md)

## Supported Platforms

| Platform | Status | Connection |
|---|---|---|
| Android | ✅ Supported | USB MIDI |
| iOS | ✅ Supported | USB MIDI |
| Linux | ✅ Supported | USB MIDI |
| Windows | ✅ Supported | USB MIDI |
| macOS | ✅ Supported | USB MIDI |
| Web | ⚠️ Limited | Web MIDI API |

## Requirements

- Flutter SDK 3.10.4+
- Dart SDK 3.10+
- DiveChecker V1 device (RP2350 Pico2)

## Getting Started

```bash
# Install dependencies
flutter pub get

# Generate localization
flutter gen-l10n

# Run
flutter run -d linux    # or android, windows, macos, ios
```

## Build

```bash
# Android APK
flutter build apk --release

# iOS
flutter build ios --release

# Linux
flutter build linux --release

# Windows
flutter build windows --release

# macOS
flutter build macos --release

# Web
flutter build web --release
```

## Project Structure

```
lib/
├── main.dart                    # App entry point
├── config/                      # Theme configuration
├── constants/                   # Constants definition
├── core/                        # DB interface
│   └── database/
├── l10n/                        # Localization (EN/KO/JA/ZH/ZH_TW)
├── models/                      # Data models
├── providers/                   # State management (Provider)
│   ├── midi_provider.dart       # USB MIDI connection
│   ├── measurement_controller.dart # Measurement logic
│   ├── session_repository.dart  # Session cache
│   ├── settings_provider.dart   # App settings
│   └── locale_provider.dart     # Language settings
├── screens/                     # Screens
│   ├── home_screen.dart         # Home (connection status)
│   ├── monitor_screen.dart      # Real-time streaming chart
│   ├── measurement_screen.dart  # Real-time measurement
│   ├── history_screen.dart      # Session history
│   ├── graph_detail_page.dart   # Detailed graph
│   ├── peak_analysis_page.dart  # Peak analysis
│   ├── settings_screen.dart     # Settings
│   ├── device_selection_screen.dart # Device selection
│   ├── device_settings_screen.dart  # Device configuration
│   └── firmware_update_screen.dart  # OTA firmware update
├── services/                    # Services
│   ├── unified_database_service.dart # DB integration
│   └── backup_service.dart      # Backup/restore
├── security/                    # Security
│   └── device_authenticator.dart # ECDSA device auth
├── utils/                       # Utilities
│   ├── chart_utils.dart         # Chart helper functions
│   └── peak_analyzer.dart       # Peak analysis algorithms
└── widgets/                     # UI components
    ├── analysis/                # Analysis widgets
    ├── common/                  # Common widgets
    ├── home/                    # Home widgets
    ├── measurement/             # Measurement widgets
    └── settings/                # Settings widgets
```

## Key Features

### 🔌 USB MIDI Communication
- Cross-platform USB MIDI support
- ECDSA device authentication
- SysEx-based data protocol
- Configurable output rate (4-50 Hz)

### 📊 Real-time Pressure Monitoring
- 100Hz internal sampling, configurable output (4-50Hz, default 8Hz)
- Real-time line chart (fl_chart) with smooth bezier curves
- Dynamic Y-axis auto-scaling on measurement & monitor charts
- Pinch zoom / drag pan gestures
- Hz-aligned grid lines
- Extended chart range up to 200 hPa

### 🔬 Peak Analysis
- Rhythm score (peak interval consistency)
- Pressure score (intensity uniformity)
- Technique score (rise/fall time)
- Fatigue index
- Overall grade (S, A, B, C, D, F)

### 💾 Data Management
- SQLite (Native) / IndexedDB (Web)
- Session recording and graph notes
- JSON backup/restore

### 🔐 Security & Reliability
- **ECDSA P-256 Authentication**: Challenge-response device verification
- **Auto-Reconnect**: Exponential backoff on USB disconnect (2/4/6s, max 3 attempts)
- **Reconnect Suppression**: Prevents auto-reconnect after intentional BOOTSEL/soft reboot
- **Non-DiveChecker Device Block**: Warning dialog for unsupported MIDI devices
- **Input Validation**: Config value range clamping
- **Timer Cleanup**: All timers cancelled on disconnect
- **Double-pop Guard**: Prevents duplicate Navigator.pop calls
- **MIDI Data Guard**: Try-catch wrapper on incoming MIDI data handler

### 🌐 Multi-language Support
- 🇺🇸 English
- 🇰🇷 Korean
- 🇯🇵 Japanese
- 🇨🇳 Simplified Chinese
- 🇹🇼 Traditional Chinese

## Testing

```bash
flutter test
```

## License

Copyright (C) 2025-2026 Createch (legal@createch.kr)

Licensed under the Apache License, Version 2.0 (the "License");
you may not use this file except in compliance with the License.
You may obtain a copy of the License at

    http://www.apache.org/licenses/LICENSE-2.0

Unless required by applicable law or agreed to in writing, software
distributed under the License is distributed on an "AS IS" BASIS,
WITHOUT WARRANTIES OR CONDITIONS OF ANY KIND, either express or implied.
See the License for the specific language governing permissions and
limitations under the License.

See the [LICENSE](../LICENSE) file in the project root for details.

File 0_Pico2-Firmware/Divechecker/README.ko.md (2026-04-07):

# DiveChecker Pico RP2350 펌웨어

Raspberry Pi Pico 2 (RP2350)용 압력 모니터링 펌웨어입니다.

[🇺🇸 English](README.md)

## 기능

- BMP280 센서로 100Hz 내부 샘플링
- 확장 측정 범위: 300-1250 hPa
- 안정적인 성능을 위한 듀얼코어 아키텍처
- 부드러운 데이터를 위한 IIR + 평균화 필터
- 연결 상태와 분리된 센서 파이프라인 (샘플링 상시 동작)
- 안전한 BOOTSEL 진입 (멀티코어 락아웃 + 인터럽트 비활성화)
- 크로스플랫폼 호환성을 위한 USB MIDI SysEx 프로토콜
- ECDSA 기기 인증
- 설정 가능한 출력 속도 (4-50 Hz)

## 요구사항

- Raspberry Pi Pico 2 (RP2350)
- BMP280 압력 센서 (I2C)
- Pico SDK

## 빌드

```bash
# Pico SDK가 없으면 클론
git clone https://github.com/raspberrypi/pico-sdk.git
cd pico-sdk
git submodule update --init

# 펌웨어 빌드
cd 0_Pico2-Firmware/Divechecker
mkdir -p build && cd build
cmake -DPICO_SDK_PATH=/path/to/pico-sdk ..
make -j4
```

출력: `Divechecker.uf2`

## 플래시

1. BOOTSEL 버튼을 누른 채로 Pico를 USB에 연결
2. `RPI-RP2` 드라이브가 나타남
3. `Divechecker.uf2`를 드라이브에 복사
4. Pico가 자동으로 재부팅

## 회로

```
Pico RP2350         BMP280 (I2C)
────────────        ────────────
3.3V         ────── VCC
GND          ────── GND
GP8 (SDA)    ────── SDA
GP9 (SCL)    ────── SCL
GP16         ────── WS2812 LED (상태 표시기)
```

## 통신 프로토콜

크로스플랫폼 호환성을 위한 USB MIDI SysEx 기반 프로토콜.

SysEx 형식: `F0 7D 01 [cmd] [data...] F7`
- 제조사 ID: `0x7D` (교육/개발용)
- 기기 ID: `0x01` (DiveChecker)

### 기기 → 앱
| 명령 | Hex | 설명 |
|---|-----|---|
| Pressure | 0x01 | 차압 (7비트 인코딩 int32, hPa×1000) |
| Device Info | 0x02 | 시리얼, 이름, FW 버전, 센서 상태 |
| Config | 0x03 | 출력 속도 응답 |
| Auth Response | 0x04 | ECDSA 서명 (니블 인코딩) |
| Over-range Alert | 0x06 | 센서 측정 범위 초과 |
| Temperature | 0x07 | BMP280 온도 (int16×100) |
| Diagnostics | 0x08 | 가동시간, 에러 카운트, I2C 복구 |
| Full Config | 0x09 | 모든 설정 가능한 파라미터 |
| ACK | 0x0A | 명령 확인 (cmd + 상태) |

### 앱 → 기기
| 명령 | Hex | 설명 |
|---|-----|---|
| Ping | 0x10 | 연결 유지 |
| Request Info | 0x20 | 기기 정보 요청 |
| Set Name | 0x21 | 기기 이름 설정 (PIN 필요) |
| Set Output Rate | 0x22 | 출력 속도 설정 (4-50 Hz) |
| Reset Baseline | 0x23 | 압력 기준점 리셋 |
| Get Config | 0x24 | 전체 설정 덤프 요청 |
| Set LED | 0x25 | LED 밝기 설정 (0-100) |
| Reset Sensor | 0x26 | 수동 센서 재초기화 |
| Factory Reset | 0x27 | 공장 초기화 (PIN 필요) |
| Set Noise Floor | 0x28 | 노이즈 임계값 설정 (0-50) |
| Get Temperature | 0x29 | 온도 요청 |
| Enter Bootloader | 0x2A | BOOTSEL 모드 진입 (PIN 필요) |
| Get Diagnostics | 0x2B | 런타임 진단 요청 |
| Set Oversampling | 0x2C | 압력 오버샘플링 설정 (0-5) |
| Set IIR Filter | 0x2D | IIR 필터 계수 설정 (0-4) |
| Soft Reboot | 0x2E | 소프트 재부팅 (PIN 필요) |
| Auth Challenge | 0x30 | ECDSA 인증 (64자 hex 논스) |
| Set PIN | 0x31 | PIN 변경 (기존 PIN + 새 PIN) |

## 키 생성

ECDSA 기기 인증용:

```bash
./generate_keys.sh
```

프로덕션 배포는 [PRODUCTION_GUIDE.md](PRODUCTION_GUIDE.md)를 참조하세요.

---

## 보안 및 안정성 기능

### 보안

| 기능 | 구현 |
|---|---|
| **ECDSA P-256 인증** | 32바이트 논스로 챌린지-응답 |
| **OTP에 개인키 저장** | 추출 불가능한 일회성 프로그래머블 저장소 |
| **상수 시간 비교** | PIN 검증으로 타이밍 공격 방지 |
| **암호 버퍼 제로화** | 사용 후 `mbedtls_platform_zeroize()` |
| **PIN Rate Limiting** | 지수 백오프 (1초 → 최대 60초) |
| **영구 잠금** | PIN 실패 횟수 재부팅 후에도 유지 |

### 안정성

| 기능 | 구현 |
|---|---|
| **워치독 타이머** | 부팅 중 8초, 운영 중 2초 |
| **센서 자동 복구** | 실패 시 5초마다 재시도 |
| **BOOTSEL 안전 종료** | 리셋 전 멀티코어 락아웃 + 인터럽트 비활성화 |
| **Flash CRC32** | 로드 시 데이터 무결성 검증 |
| **마모 평준화** | 4KB 섹터 내 16슬롯 로테이션 |
| **Flash 쓰기 디바운스** | 빠른 쓰기 방지를 위한 3초 지연 |
| **부팅 시 Flash 컴팩션** | 랩어라운드 구간의 erase 부담을 부팅 시점으로 이동 |
| **락아웃 후 I2C 유예 구간** | flash lockout 직후 일시적 NaN 샘플 무시 |
| **연속 센서 파이프라인** | 앱 연결 해제 중에도 Core 1 샘플링/필터링 지속 |
| **연결 타임아웃 여유** | keepalive 타임아웃 30초 (CONNECTION_TIMEOUT_MS)로 UI 지연 허용 |
| **SysEx 타임아웃** | 500ms 파서 리셋 (모든 상태) |
| **PIO 폴백** | PIO0 사용 불가 시 PIO1로 자동 전환 |

### 성능

| 지표 | 값 |
|---|-----|
| **내부 샘플링** | 100Hz (BMP280) |
| **측정 범위** | 300-1250 hPa (데이터시트 1100 hPa 스펙 초과 확장) |
| **출력 속도** | 4-50Hz (설정 가능) |
| **센서→앱 지연** | ~10ms |
| **Core 0** | USB MIDI + 명령 처리 |
| **Core 1** | 센서 샘플링 + IIR 필터링 |
| **코어간 통신** | 락프리 FIFO 큐 |

### 메모리 레이아웃

```
Flash (총 4MB)
├── 0x000000-0x3FEFFF: 애플리케이션 코드 + 데이터
└── 0x3FF000-0x3FFFFF: 설정 섹터 (4KB)
    └── 16 × 256바이트 슬롯 (마모 평준화)
        ├── magic (4B)
        ├── PIN (5B)
        ├── name (25B)
        ├── config (8B)
        ├── reserved (210B)
        └── CRC32 (4B)
```

## 라이선스

Copyright (C) 2025-2026 Createch (legal@createch.kr)

Apache License 2.0 (소프트웨어) 및 CERN-OHL-S v2 (하드웨어)에 따라 라이선스됩니다.

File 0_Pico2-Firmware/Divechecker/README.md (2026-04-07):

# DiveChecker Pico RP2350 Firmware

Pressure monitoring firmware for Raspberry Pi Pico 2 (RP2350).

[🇰🇷 한국어](README.ko.md)

## Features

- 100Hz internal sampling with BMP280 sensor
- Extended measurement range: 300-1250 hPa
- Dual-core architecture for stable performance
- IIR + Averaging filter for smooth data
- Connection-decoupled sensor pipeline (sampling always on)
- Safe BOOTSEL entry (multicore lockout + interrupt disable)
- USB MIDI SysEx protocol for cross-platform compatibility
- ECDSA device authentication
- Configurable output rate (4-50 Hz)

## Requirements

- Raspberry Pi Pico 2 (RP2350)
- BMP280 pressure sensor (I2C)
- Pico SDK

## Build

```bash
# Clone Pico SDK if not already installed
git clone https://github.com/raspberrypi/pico-sdk.git
cd pico-sdk
git submodule update --init

# Build firmware
cd 0_Pico2-Firmware/Divechecker
mkdir -p build && cd build
cmake -DPICO_SDK_PATH=/path/to/pico-sdk ..
make -j4
```

Output: `Divechecker.uf2`

## Flash

1. Hold BOOTSEL button while connecting Pico to USB
2. `RPI-RP2` drive will appear
3. Copy `Divechecker.uf2` to the drive
4. Pico will reboot automatically

## Circuit

```
Pico RP2350         BMP280 (I2C)
────────────        ────────────
3.3V         ────── VCC
GND          ────── GND
GP8 (SDA)    ────── SDA
GP9 (SCL)    ────── SCL
GP16         ────── WS2812 LED (status indicator)
```

## Communication Protocol

USB MIDI SysEx-based protocol for cross-platform compatibility.

SysEx format: `F0 7D 01 [cmd] [data...] F7`
- Manufacturer ID: `0x7D` (educational/development)
- Device ID: `0x01` (DiveChecker)

### Device → App
| Command | Hex | Description |
|---|-----|---|
| Pressure | 0x01 | Delta pressure (7-bit encoded int32, hPa×1000) |
| Device Info | 0x02 | Serial, name, FW version, sensor status |
| Config | 0x03 | Output rate response |
| Auth Response | 0x04 | ECDSA signature (nibble-encoded) |
| Over-range Alert | 0x06 | Sensor exceeded measurement range |
| Temperature | 0x07 | BMP280 temperature (int16×100) |
| Diagnostics | 0x08 | Uptime, error counts, I2C recovery |
| Full Config | 0x09 | All configurable parameters |
| ACK | 0x0A | Command acknowledgment (cmd + status) |

### App → Device
| Command | Hex | Description |
|---|-----|---|
| Ping | 0x10 | Connection keepalive |
| Request Info | 0x20 | Request device info |
| Set Name | 0x21 | Set device name (PIN required) |
| Set Output Rate | 0x22 | Set output rate (4-50 Hz) |
| Reset Baseline | 0x23 | Reset pressure baseline |
| Get Config | 0x24 | Request full config dump |
| Set LED | 0x25 | Set LED brightness (0-100) |
| Reset Sensor | 0x26 | Manual sensor re-init |
| Factory Reset | 0x27 | Factory reset (PIN required) |
| Set Noise Floor | 0x28 | Set noise threshold (0-50) |
| Get Temperature | 0x29 | Request temperature |
| Enter Bootloader | 0x2A | Enter BOOTSEL mode (PIN required) |
| Get Diagnostics | 0x2B | Request runtime diagnostics |
| Set Oversampling | 0x2C | Set pressure oversampling (0-5) |
| Set IIR Filter | 0x2D | Set IIR filter coefficient (0-4) |
| Soft Reboot | 0x2E | Soft reboot (PIN required) |
| Auth Challenge | 0x30 | ECDSA auth (64-char hex nonce) |
| Set PIN | 0x31 | Change PIN (old PIN + new PIN) |

## Key Generation

For ECDSA device authentication:

```bash
./generate_keys.sh
```

See [PRODUCTION_GUIDE.md](PRODUCTION_GUIDE.md) for production deployment.

---

## Security & Reliability Features

### Security

| Feature | Implementation |
|---|---|
| **ECDSA P-256 Auth** | Challenge-response with 32-byte nonce |
| **Private Key in OTP** | Non-extractable one-time programmable storage |
| **Constant-Time Compare** | PIN verification prevents timing attacks |
| **Crypto Buffer Zeroing** | `mbedtls_platform_zeroize()` after use |
| **PIN Rate Limiting** | Exponential backoff (1s → 60s max) |
| **Persistent Lockout** | PIN failure count survives reboot |

### Reliability

| Feature | Implementation |
|---|---|
| **Watchdog Timer** | 8s during boot, 2s during operation |
| **Sensor Auto-Recovery** | 5-second periodic retry on failure |
| **BOOTSEL Safe Shutdown** | Multicore lockout + interrupt disable before reset |
| **Flash CRC32** | Data integrity verification on load |
| **Wear Leveling** | 16-slot rotation in 4KB sector |
| **Flash Write Debounce** | 3-second delay prevents rapid writes |
| **Boot-Time Flash Compaction** | Erase-heavy wrap-around writes are moved to boot |
| **Lockout I2C Grace Window** | Transient NaN samples after flash lockout are ignored |
| **Continuous Sensor Pipeline** | Core 1 sampling/filtering runs even when app disconnects |
| **Connection Timeout Margin** | Keepalive timeout 30s (CONNECTION_TIMEOUT_MS) to tolerate UI jitter |
| **SysEx Timeout** | 500ms parser reset (all states) |
| **PIO Fallback** | Auto-switch to PIO1 if PIO0 unavailable |

### Performance

| Metric | Value |
|---|---|
| **Internal Sampling** | 100Hz (BMP280) |
| **Measurement Range** | 300-1250 hPa (extended beyond 1100 hPa datasheet spec) |
| **Output Rate** | 4-50Hz (configurable) |
| **Sensor-to-App Latency** | ~10ms |
| **Core 0** | USB MIDI + Command processing |
| **Core 1** | Sensor sampling + IIR filtering |
| **Inter-Core** | Lock-free FIFO queue |

### Memory Layout

```
Flash (4MB total)
├── 0x000000-0x3FEFFF: Application code + data
└── 0x3FF000-0x3FFFFF: Settings sector (4KB)
    └── 16 × 256-byte slots (wear leveling)
        ├── magic (4B)
        ├── PIN (5B)
        ├── name (25B)
        ├── config (8B)
        ├── reserved (210B)
        └── CRC32 (4B)
```

## License

Copyright (C) 2025-2026 Createch (legal@createch.kr)

Licensed under Apache License 2.0 (Software) and CERN-OHL-S v2 (Hardware).

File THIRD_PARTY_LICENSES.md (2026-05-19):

# Third-Party Licenses

DiveChecker software is licensed under [Apache License 2.0](LICENSE) and the hardware design under [CERN-OHL-S v2](https://ohwr.org/cern_ohl_s_v2.txt). This document lists the third-party components redistributed or pulled in as runtime/build dependencies, together with their upstream licenses.

## Firmware — Pico SDK + pulled libraries

### Pico SDK 2.2.0

- Upstream: <https://github.com/raspberrypi/pico-sdk>
- License: BSD-3-Clause
- Role: RP2350 (Pico 2) board support package — `pico_stdlib`, USB stack glue, multicore, hardware peripherals.

### TinyUSB

- Upstream: <https://github.com/hathach/tinyusb>
- License: MIT
- Vendored via Pico SDK
- Role: USB Device stack used to expose DiveChecker as a USB MIDI class device. See `0_Pico2-Firmware/Divechecker/usb_descriptors.c`.

### Mbed TLS

- Upstream: <https://github.com/Mbed-TLS/mbedtls>
- License: Apache-2.0
- Vendored via Pico SDK (`${PICO_SDK_PATH}/lib/mbedtls`)
- Role: ECDSA P-256 challenge/response device authentication. Subset compiled with custom `mbedtls_config.h` for footprint.

## App — Flutter pub packages

Managed via `_0_DiveChecker-APP/pubspec.yaml`. Each upstream's full license is in `pub.dev` and the `.pub-cache` lockfile.

| Package | License | Use |
|---|---|-----|
| `flutter_midi_command` ^0.5.3 | MIT | USB MIDI SysEx I/O on Android / iOS / macOS / Windows / Linux |
| `permission_handler` ^11.3.1 | MIT | Runtime permissions on mobile |
| `fl_chart` ^0.70.2 | MIT | Real-time pressure visualization |
| `sqflite` ^2.4.2 | MIT | Native SQLite |
| `sqflite_common_ffi` ^2.3.4+5 | MIT | SQLite on desktop (Linux/Windows/macOS) |
| `idb_shim` ^2.6.1+1 | BSD-3-Clause | IndexedDB shim on Web |
| `path` ^1.9.1 | BSD-3-Clause | Path manipulation |
| `path_provider` ^2.1.5 | BSD-3-Clause | Platform path discovery |
| `file_picker` ^8.1.7 | MIT | JSON backup/restore file picking |
| `provider` ^6.1.4 | MIT | State management |
| `pointycastle` (transitive) | MIT | ECDSA P-256 signature verification on the app side |
| `cupertino_icons` ^1.0.8 | MIT | iOS-style icons |

Flutter SDK itself is BSD-3-Clause (<https://github.com/flutter/flutter/blob/master/LICENSE>).

## Linux Flutter plugin override

`packages/flutter_midi_command_linux/` is a custom fork to support ALSA RawMIDI on Linux desktop. Forked from `flutter_midi_command_linux` (MIT). Modifications preserved under the same license.

## Marketing site (`website/`)

- Inter font — SIL Open Font License 1.1 (<https://github.com/rsms/inter>)
- Noto Sans KR — SIL Open Font License 1.1 (<https://fonts.google.com/noto>)
- All other assets (logo, hero renders, OG images) © 2025-2026 Createch — All rights reserved.

## Hardware (`0_CAD/`)

DiveChecker enclosure (V4–V11) is **CERN-OHL-S v2**. FreeCAD files reference the BME280 5V breakout module footprint; no proprietary symbols redistributed.

## Attribution

Build dependencies discovered automatically via the package manager (`flutter pub get` / Pico SDK install) are not listed individually here. For an exhaustive transitive list, see:

- `_0_DiveChecker-APP/pubspec.lock` (Flutter deps)
- `${PICO_SDK_PATH}/LICENSE.TXT` and the `mbedtls/`, `tinyusb/` subtrees (firmware deps)

If you find a dependency missing or mis-attributed, please open an issue at <https://github.com/kernalix7/DiveChecker/issues>.

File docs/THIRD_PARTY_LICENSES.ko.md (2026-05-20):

# 서드파티 라이선스

[English](../THIRD_PARTY_LICENSES.md) | **한국어**

DiveChecker 소프트웨어는 [Apache License 2.0](../LICENSE), 하드웨어 설계는 [CERN-OHL-S v2](https://ohwr.org/cern_ohl_s_v2.txt)로 라이선스됩니다. 이 문서는 소스 트리 내 재배포되거나 런타임/빌드 의존성으로 끌어다 쓰는 서드파티 구성요소를 업스트림 라이선스와 함께 나열합니다.

## 펌웨어 — Pico SDK + 사용 라이브러리

### Pico SDK 2.2.0

- Upstream: <https://github.com/raspberrypi/pico-sdk>
- License: BSD-3-Clause
- 역할: RP2350 (Pico 2) 보드 지원 패키지 — `pico_stdlib`, USB 스택, 멀티코어, 하드웨어 페리페럴.

### TinyUSB

- Upstream: <https://github.com/hathach/tinyusb>
- License: MIT
- 벤더링: Pico SDK 경유
- 역할: DiveChecker를 USB MIDI class device로 노출시키는 USB Device 스택. `0_Pico2-Firmware/Divechecker/usb_descriptors.c` 참조.

### Mbed TLS

- Upstream: <https://github.com/Mbed-TLS/mbedtls>
- License: Apache-2.0
- 벤더링: Pico SDK 경유 (`${PICO_SDK_PATH}/lib/mbedtls`)
- 역할: ECDSA P-256 challenge/response 디바이스 인증. 메모리 footprint를 위해 커스텀 `mbedtls_config.h`로 서브셋만 컴파일.

## 앱 — Flutter pub 패키지

`_0_DiveChecker-APP/pubspec.yaml`에서 관리. 각 업스트림 전체 라이선스는 `pub.dev` 및 `.pub-cache` lockfile에서 확인 가능.

| 패키지 | 라이선스 | 용도 |
|---|---|---|
| `flutter_midi_command` ^0.5.3 | MIT | Android / iOS / macOS / Windows / Linux에서 USB MIDI SysEx I/O |
| `permission_handler` ^11.3.1 | MIT | 모바일 런타임 권한 |
| `fl_chart` ^0.70.2 | MIT | 실시간 압력 시각화 |
| `sqflite` ^2.4.2 | MIT | 네이티브 SQLite |
| `sqflite_common_ffi` ^2.3.4+5 | MIT | 데스크탑(Linux/Windows/macOS) SQLite |
| `idb_shim` ^2.6.1+1 | BSD-3-Clause | Web IndexedDB shim |
| `path` ^1.9.1 | BSD-3-Clause | 경로 조작 |
| `path_provider` ^2.1.5 | BSD-3-Clause | 플랫폼별 경로 탐지 |
| `file_picker` ^8.1.7 | MIT | JSON 백업/복원 파일 선택 |
| `provider` ^6.1.4 | MIT | 상태 관리 |
| `pointycastle` (transitive) | MIT | 앱 측 ECDSA P-256 서명 검증 |
| `cupertino_icons` ^1.0.8 | MIT | iOS 스타일 아이콘 |

Flutter SDK 자체는 BSD-3-Clause (<https://github.com/flutter/flutter/blob/master/LICENSE>).

## Linux Flutter plugin override

`packages/flutter_midi_command_linux/`는 Linux 데스크탑 ALSA RawMIDI 지원을 위해 커스텀 fork. 원본 `flutter_midi_command_linux` (MIT)에서 fork. 동일 라이선스 유지.

## 마케팅 사이트 (`website/`)

- Inter 폰트 — SIL Open Font License 1.1 (<https://github.com/rsms/inter>)
- Noto Sans KR — SIL Open Font License 1.1 (<https://fonts.google.com/noto>)
- 그 외 자산 (로고, 히어로 렌더, OG 이미지) © 2025-2026 Createch — All rights reserved.

## 하드웨어 (`0_CAD/`)

DiveChecker 케이스 (V4–V11)는 **CERN-OHL-S v2**. FreeCAD 파일은 BME280 5V breakout 모듈 footprint를 참조하며, 독점 심볼은 재배포하지 않음.

## Attribution

패키지 매니저(`flutter pub get` / Pico SDK 설치)로 자동 발견되는 빌드 의존성은 여기에 개별 나열하지 않음. 전체 transitive 목록은 다음을 참조:

- `_0_DiveChecker-APP/pubspec.lock` (Flutter 의존성)
- `${PICO_SDK_PATH}/LICENSE.TXT` 및 `mbedtls/`, `tinyusb/` 서브트리 (펌웨어 의존성)

누락 / 잘못 표기된 의존성을 발견하시면 <https://github.com/kernalix7/DiveChecker/issues>에 이슈 등록 부탁드립니다.

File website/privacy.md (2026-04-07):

# Privacy Policy

**English** | [한국어](PRIVACY_POLICY.ko.md)

**Effective Date: March 26, 2026**

## Introduction

DiveChecker ("the App") is a freediving equalization pressure monitoring application developed by Createch ("we", "us", "our"). This Privacy Policy explains how the App handles user information.

## Data Collection

**The App does not collect, transmit, or share any personal data.**

All data generated by the App — including pressure measurement sessions, chart annotations, and user preferences — is stored **exclusively on your device** in local storage (SQLite database and SharedPreferences). No data is sent to external servers, cloud services, or third parties.

## Network Access

The App does **not** require internet access. The release build does not include the `INTERNET` permission. The App functions entirely offline.

## Hardware Communication

The App communicates with the DiveChecker hardware device via **USB MIDI** connection only. This communication occurs locally between your device and the connected hardware. No data from this communication is transmitted over any network.

## Device Authentication

The App uses ECDSA P-256 cryptographic signature verification to authenticate connected DiveChecker hardware devices. This process is performed locally on-device and does not involve any external servers.

## Third-Party Services

The App does **not** integrate with any third-party analytics, advertising, crash reporting, or tracking services. There are no third-party SDKs that collect user data.

## Data Storage and Retention

- **Measurement data**: Stored locally in SQLite database on your device
- **User preferences**: Stored locally via SharedPreferences (theme, language, notification settings, etc.)
- **Data export**: You may manually export measurement data as JSON files to your device's storage. This is entirely user-initiated and remains on your device.

You can delete all app data at any time by clearing the app's data through your device settings or by uninstalling the App.

## Children's Privacy

The App is not directed at children under the age of 13. It is a specialized tool designed for freediving training that requires dedicated hardware equipment.

## Changes to This Policy

We may update this Privacy Policy from time to time. Any changes will be reflected in this document with an updated effective date.

## Contact

If you have any questions about this Privacy Policy, please contact us:

- Email: cs-divechecker@createch.kr
- GitHub: [https://github.com/kernalix7/DiveChecker](https://github.com/kernalix7/DiveChecker)

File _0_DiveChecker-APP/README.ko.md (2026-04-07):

# DiveChecker Flutter 앱

프리다이빙 이퀄라이징 훈련을 위한 크로스플랫폼 압력 모니터링 앱입니다.

[🇺🇸 English](README.md)

## 지원 플랫폼

| 플랫폼 | 상태 | 연결 |
|---|---|---|
| Android | ✅ 지원 | USB MIDI |
| iOS | ✅ 지원 | USB MIDI |
| Linux | ✅ 지원 | USB MIDI |
| Windows | ✅ 지원 | USB MIDI |
| macOS | ✅ 지원 | USB MIDI |
| Web | ⚠️ 제한적 | Web MIDI API |

## 요구사항

- Flutter SDK 3.10.4+
- Dart SDK 3.0+
- DiveChecker V1 기기 (RP2350 Pico2)

## 시작하기

```bash
# 의존성 설치
flutter pub get

# 로컬라이제이션 생성
flutter gen-l10n

# 실행
flutter run -d linux    # 또는 android, windows, macos, ios
```

## 빌드

```bash
# Android APK
flutter build apk --release

# iOS
flutter build ios --release

# Linux
flutter build linux --release

# Windows
flutter build windows --release

# macOS
flutter build macos --release
```

## 프로젝트 구조

```
lib/
├── main.dart                    # 앱 진입점
├── config/                      # 테마 설정
├── constants/                   # 상수 정의
├── core/                        # DB 인터페이스
│   └── database/
├── l10n/                        # 다국어 지원 (EN/KO/JA/ZH/ZH_TW)
├── models/                      # 데이터 모델
├── providers/                   # 상태 관리 (Provider)
│   ├── midi_provider.dart       # USB MIDI 연결
│   ├── measurement_controller.dart # 측정 로직
│   ├── session_repository.dart  # 세션 캐시
│   ├── settings_provider.dart   # 앱 설정
│   └── locale_provider.dart     # 언어 설정
├── screens/                     # 화면
│   ├── home_screen.dart         # 홈 (연결 상태)
│   ├── monitor_screen.dart      # 실시간 스트리밍 차트
│   ├── measurement_screen.dart  # 실시간 측정
│   ├── history_screen.dart      # 세션 기록
│   ├── graph_detail_page.dart   # 상세 그래프
│   ├── peak_analysis_page.dart  # 피크 분석
│   ├── settings_screen.dart     # 설정
│   ├── device_selection_screen.dart # 장치 선택
│   ├── device_settings_screen.dart  # 장치 설정
│   └── firmware_update_screen.dart  # OTA 펌웨어 업데이트
├── services/                    # 서비스
│   ├── unified_database_service.dart # DB 통합
│   └── backup_service.dart      # 백업/복원
├── security/                    # 보안
│   └── device_authenticator.dart # ECDSA 기기 인증
├── utils/                       # 유틸리티
│   ├── chart_utils.dart         # 차트 헬퍼 함수
│   └── peak_analyzer.dart       # 피크 분석 알고리즘
└── widgets/                     # UI 컴포넌트
    ├── analysis/                # 분석 위젯
    ├── common/                  # 공통 위젯
    ├── home/                    # 홈 위젯
    ├── measurement/             # 측정 위젯
    └── settings/                # 설정 위젯
```

## 주요 기능

### 🔌 USB MIDI 통신
- 크로스플랫폼 USB MIDI 지원
- ECDSA 기기 인증
- SysEx 기반 데이터 프로토콜
- 출력 속도 설정 가능 (4-50 Hz)

### 📊 실시간 압력 모니터링
- 160Hz 내부 샘플링, 설정 가능 출력 (4-50Hz, 기본 8Hz)
- 실시간 라인 차트 (fl_chart) 부드러운 베지어 곡선
- 측정/모니터 차트 동적 Y축 자동 스케일링
- 핀치 줌 / 드래그 팬 제스처
- Hz 기준 그리드 라인
- 차트 범위 200 hPa까지 확장

### 🔬 피크 분석
- 리듬 점수 (피크 간격 일관성)
- 압력 점수 (강도 균일성)
- 테크닉 점수 (상승/하강 시간)
- 피로도 지수
- 종합 등급 (S, A, B, C, D, F)

### 💾 데이터 관리
- SQLite (Native) / IndexedDB (Web)
- 세션 기록 및 그래프 노트
- JSON 백업/복원

### 🔐 보안 및 안정성
- **ECDSA P-256 인증**: 챌린지-응답 기기 검증
- **자동 재연결**: USB 끊김 시 지수 백오프 (2/4/6초, 최대 3회)
- **재연결 억제**: BOOTSEL/소프트 재부팅 후 자동 재연결 방지
- **비-DiveChecker 기기 차단**: 지원되지 않는 MIDI 기기 경고 다이얼로그
- **입력 검증**: 설정값 범위 제한 (clamp)
- **타이머 정리**: 연결 해제 시 모든 타이머 취소
- **Double-pop 방지**: Navigator.pop 중복 호출 방지
- **MIDI 데이터 보호**: 수신 MIDI 데이터 핸들러 try-catch 래핑

### 🌐 다국어 지원
- 🇺🇸 English
- 🇰🇷 한국어
- 🇯🇵 日本語
- 🇨🇳 简体中文
- 🇹🇼 繁體中文

## 테스트

```bash
# 단위 테스트
flutter test

# 통합 테스트
flutter test integration_test/
```

## 라이선스

Copyright (C) 2025-2026 Createch (legal@createch.kr)

Apache License 2.0에 따라 라이선스가 부여됩니다.

자세한 내용은 프로젝트 루트의 [LICENSE](../LICENSE) 파일을 참조하세요.

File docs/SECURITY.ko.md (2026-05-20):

# 보안 정책

[English](../SECURITY.md) | **한국어**

## 지원 버전

| 버전 | 지원 여부 |
|---|---|
| 최신 | Yes |

DiveChecker는 활발히 개발 중이며, 보안 업데이트는 `main` 브랜치의 최신 버전에 적용됩니다.

## 취약점 제보 방법

보안 취약점은 GitHub Security Advisories를 통해 제보해 주세요:

**[취약점 제보하기](https://github.com/kernalix7/DiveChecker/security/advisories/new)**

**보안 취약점은 공개 GitHub 이슈로 제보하지 마세요.**

### 제보 시 포함할 내용

- **설명**: 취약점에 대한 명확한 설명
- **재현 단계**: 문제를 재현하기 위한 상세 단계
- **영향**: 취약점의 잠재적 영향
- **영향받는 구성요소**: 앱 / 펌웨어 / 하드웨어 / 마케팅 사이트
- **환경**:
  - OS 및 버전
  - 앱 버전 (Flutter)
  - 펌웨어 버전 (RP2350)
  - 디바이스 모델 (DC-EQ01 / Vent)
  - 연결 방식 (USB-C / Lightning 어댑터)

## 대응 일정

| 단계 | 기간 |
|---|-----|
| 접수 확인 | 48시간 이내 |
| 초기 평가 | 7일 이내 |
| 수정 | 30일 이내 |

## 범위

In-scope:

- ECDSA P-256 디바이스 인증 우회 또는 키 추출
- USB MIDI SysEx 프로토콜 인젝션 또는 버퍼 오버플로우
- 펌웨어 메모리 손상 또는 코드 실행
- Flutter 앱 데이터 유출 (세션 데이터, 디바이스 키)
- 크로스플랫폼 데이터베이스 (SQLite/IndexedDB) 인젝션
- RP2350 OTP 키 저장소 취약점
- 불안전한 펌웨어 업데이트 메커니즘
- USB 통신 가로채기 / 재전송 공격
- 마케팅 사이트 (divechecker.createch.kr): XSS, CSP 우회, 공급망 (CDN/의존성) 공격

Out of scope:

- 사용자 호스트 머신에 물리적 접근이 필요한 버그
- 소셜 엔지니어링 공격
- 서드파티 의존성의 문제 (업스트림에 제보해 주시되, 알려주시면 감사합니다)

## 보안 모범 사례

DiveChecker가 따르는 관행:

- **ECDSA P-256 디바이스 인증** — 정품 하드웨어의 암호학적 검증
- **OTP 키 저장** — 프로덕션 키는 RP2350 일회성 프로그래밍 메모리에 저장
- **펌웨어 동적 메모리 미사용** — 고정 크기 버퍼로 힙 기반 공격 방지
- **입력 검증** — 모든 SysEx 명령은 처리 전 검증
- **PIN 보호 설정** — 디바이스 설정 변경 시 PIN 인증 필요
- **네트워크 통신 없음** — 순수 USB 연결, 클라우드/인터넷 의존성 없음
- **사이트 CSP + canonical URLs** — 마케팅 사이트는 canonical href + OG/Twitter meta만 사용

## 감사의 말

책임감 있는 취약점 공개에 힘써주시는 보안 연구 커뮤니티에 감사드립니다. 유효한 보안 이슈를 제보해 주신 분은 (동의 시) 릴리스 노트에서 감사를 표합니다.

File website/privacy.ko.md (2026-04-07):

# 개인정보처리방침

[English](PRIVACY_POLICY.md) | **한국어**

**시행일: 2026년 3월 26일**

## 소개

DiveChecker("본 앱")는 크리에이테크 (Createch)("당사")가 개발한 프리다이빙 이퀄라이징 압력 모니터링 애플리케이션입니다. 본 개인정보처리방침은 앱의 정보 처리 방식을 설명합니다.

## 데이터 수집

**본 앱은 어떠한 개인정보도 수집, 전송, 공유하지 않습니다.**

앱에서 생성되는 모든 데이터 — 압력 측정 세션, 차트 메모, 사용자 설정 등 — 는 **기기의 로컬 저장소**에만 저장됩니다(SQLite 데이터베이스 및 SharedPreferences). 외부 서버, 클라우드 서비스 또는 제3자에게 데이터를 전송하지 않습니다.

## 네트워크 접근

본 앱은 인터넷 접근을 **필요로 하지 않습니다.** 릴리즈 빌드에는 `INTERNET` 권한이 포함되지 않으며, 앱은 완전히 오프라인으로 동작합니다.

## 하드웨어 통신

앱은 **USB MIDI** 연결을 통해서만 DiveChecker 하드웨어 장치와 통신합니다. 이 통신은 기기와 연결된 하드웨어 간에 로컬로 수행되며, 어떠한 네트워크를 통해서도 데이터가 전송되지 않습니다.

## 기기 인증

앱은 ECDSA P-256 암호화 서명 검증을 사용하여 연결된 DiveChecker 하드웨어 장치를 인증합니다. 이 과정은 기기 내에서 로컬로 수행되며 외부 서버를 사용하지 않습니다.

## 제3자 서비스

본 앱은 제3자 분석, 광고, 크래시 리포팅 또는 추적 서비스를 **통합하지 않습니다.** 사용자 데이터를 수집하는 제3자 SDK가 없습니다.

## 데이터 저장 및 보관

- **측정 데이터**: 기기의 SQLite 데이터베이스에 로컬 저장
- **사용자 설정**: SharedPreferences를 통해 로컬 저장 (테마, 언어, 알림 설정 등)
- **데이터 내보내기**: 측정 데이터를 JSON 파일로 기기 저장소에 수동 내보내기 가능. 이는 전적으로 사용자가 시작하는 작업이며 기기에 보관됩니다.

기기 설정에서 앱 데이터를 삭제하거나 앱을 제거하면 언제든지 모든 앱 데이터를 삭제할 수 있습니다.

## 아동 개인정보

본 앱은 13세 미만의 아동을 대상으로 하지 않습니다. 전용 하드웨어 장비가 필요한 프리다이빙 훈련용 전문 도구입니다.

## 정책 변경

본 개인정보처리방침은 수시로 업데이트될 수 있습니다. 변경 사항은 시행일 업데이트와 함께 본 문서에 반영됩니다.

## 연락처

본 개인정보처리방침에 대한 문의사항은 아래로 연락해 주시기 바랍니다:

- 이메일: cs-divechecker@createch.kr
- GitHub: [https://github.com/kernalix7/DiveChecker](https://github.com/kernalix7/DiveChecker)

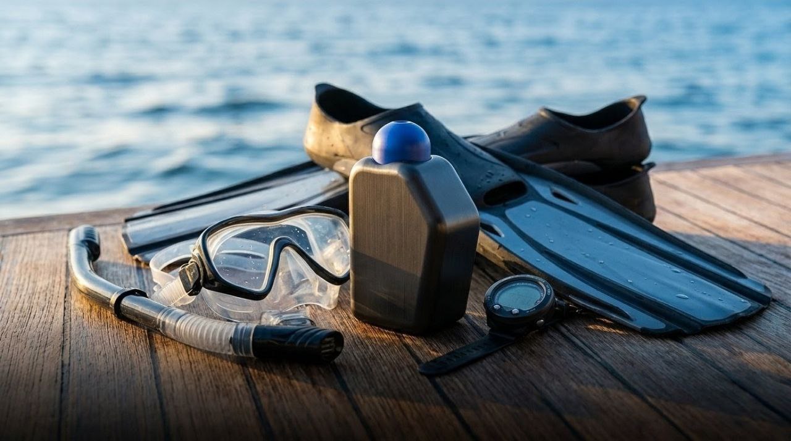
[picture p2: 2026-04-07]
website/assets/images/lifestyle.jpg

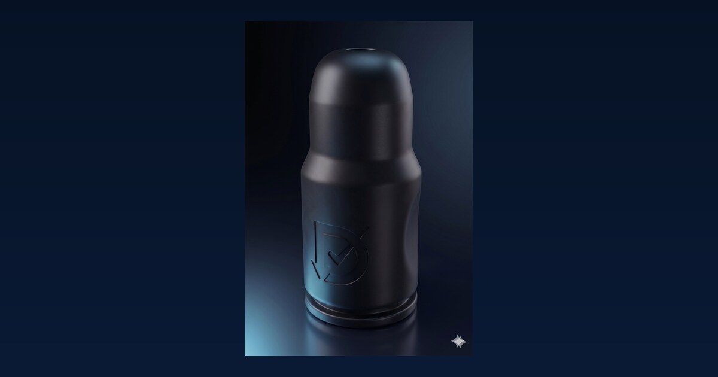
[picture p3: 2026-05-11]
website/assets/images/og-vent.jpg

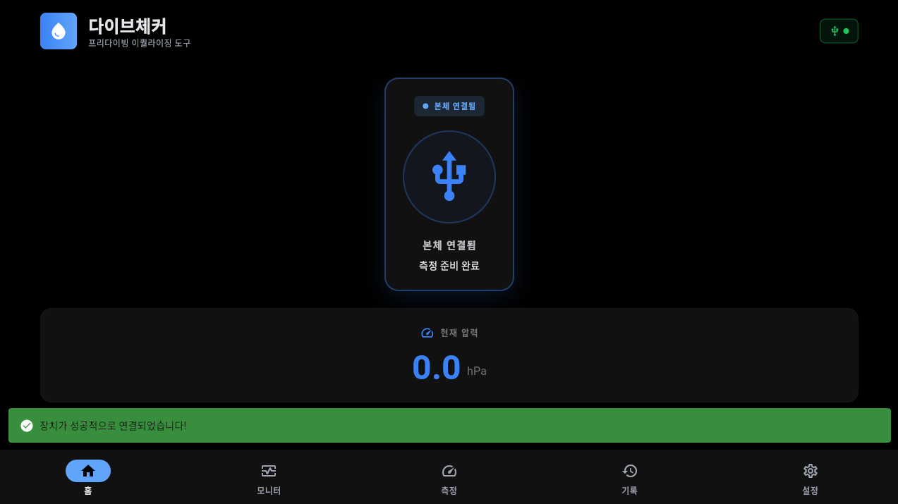
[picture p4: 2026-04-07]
website/assets/images/app-mockup.png

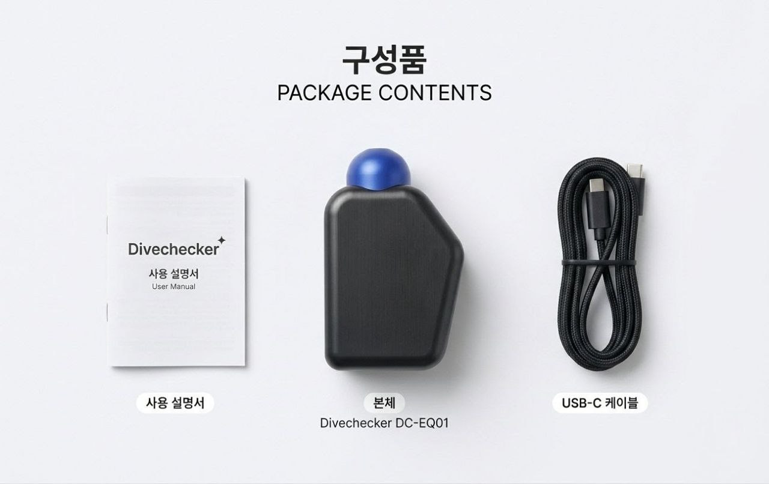
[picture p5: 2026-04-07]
website/assets/images/package-contents.jpg

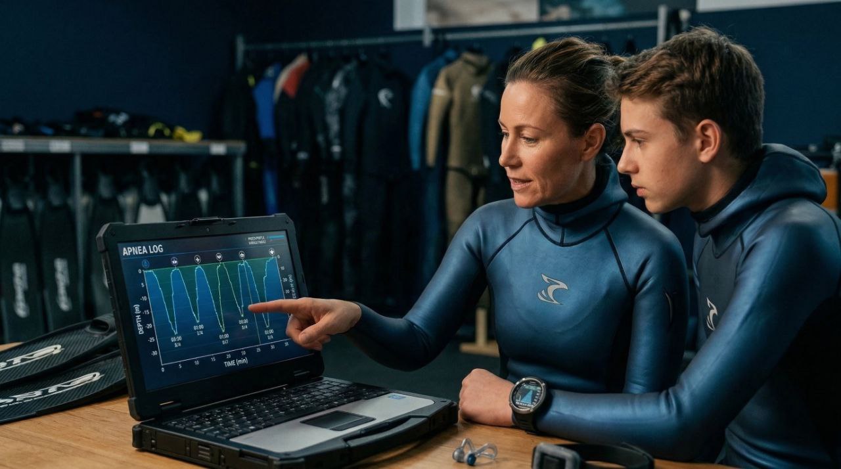
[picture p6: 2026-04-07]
website/assets/images/feature-analysis.jpg

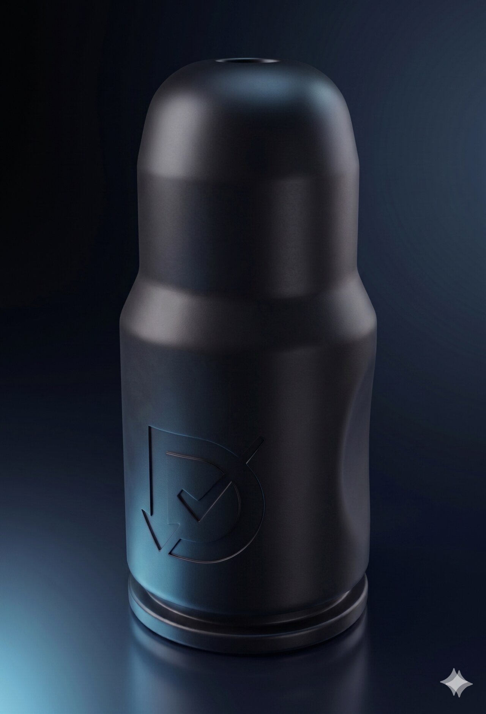
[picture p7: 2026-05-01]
website/assets/images/vent-hero.jpg

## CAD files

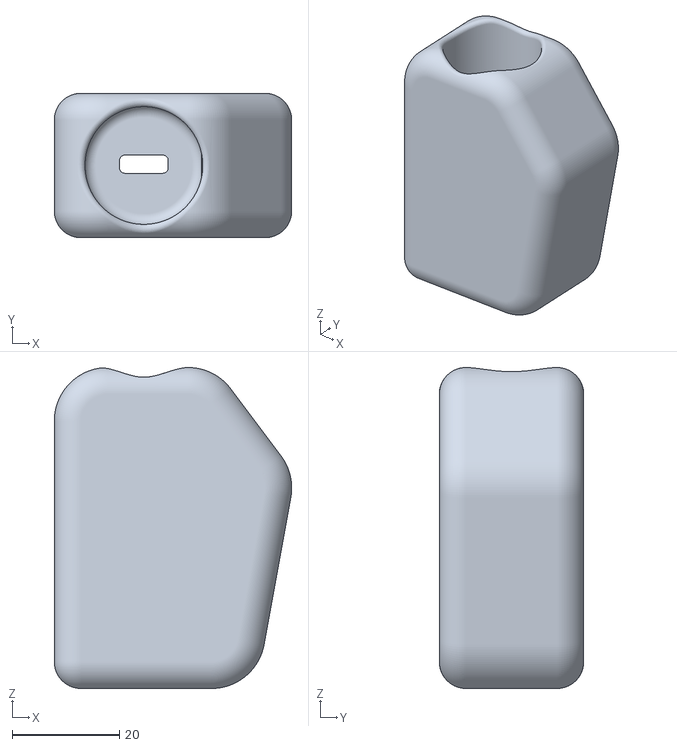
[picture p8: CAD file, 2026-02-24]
0_CAD/Device_V10-Main-body.stl
44.4 x 27.0 x 60.0

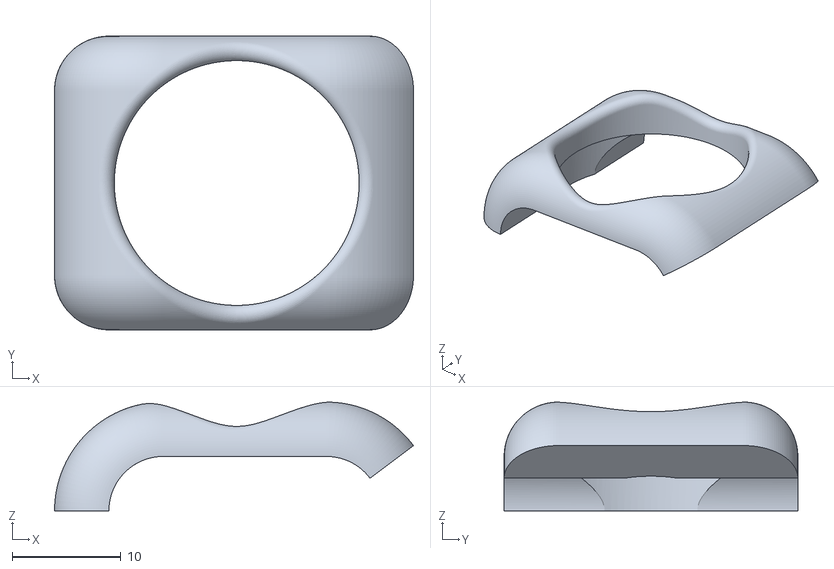
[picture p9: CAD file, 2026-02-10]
0_CAD/Device_V7-1-Main-body001.stl
33.0 x 27.0 x 9.99

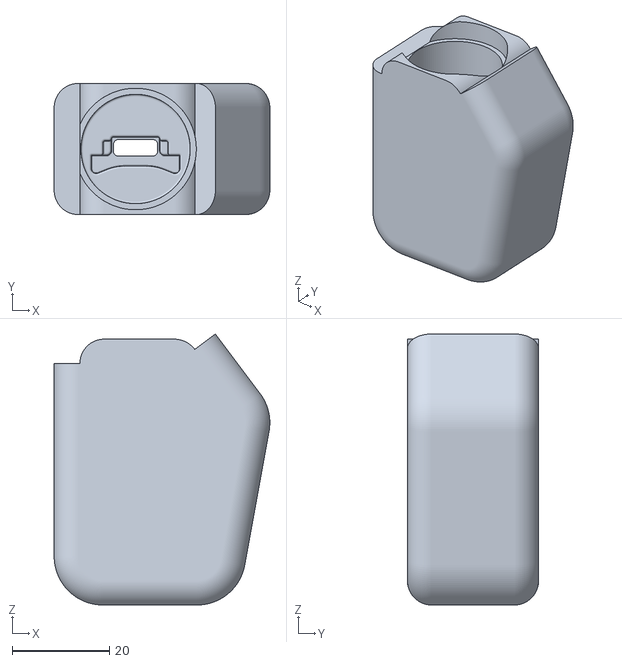
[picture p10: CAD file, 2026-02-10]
0_CAD/Device_V7-1-Main-body.stl
44.4 x 27.0 x 55.8

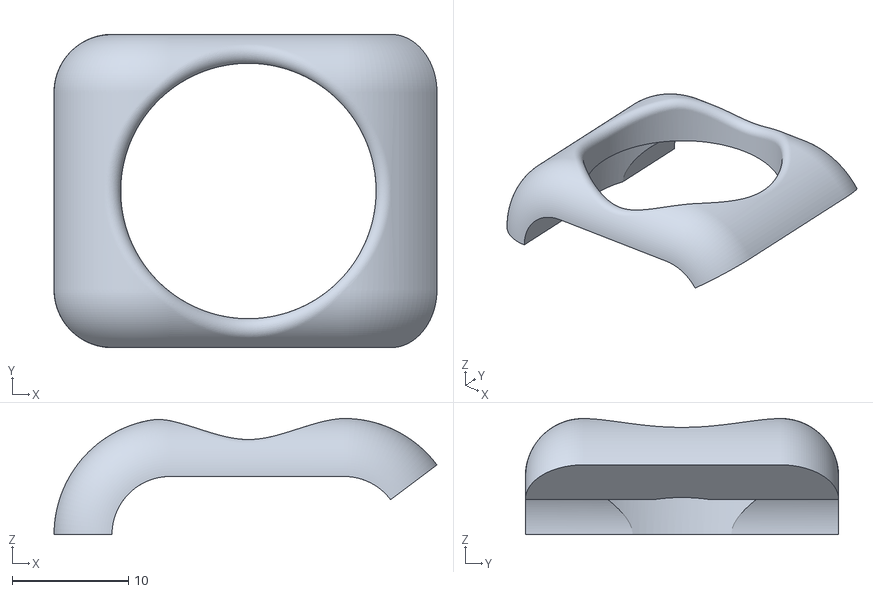
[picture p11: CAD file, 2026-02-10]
0_CAD/Device_V7-Main-body001.stl
33.0 x 27.0 x 10.00

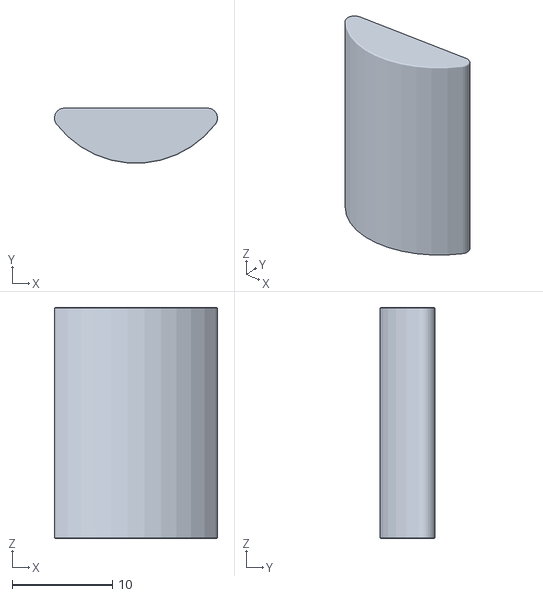
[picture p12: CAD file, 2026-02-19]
0_CAD/Device_V9-Core-sub.stl
16.2 x 5.47 x 23.0

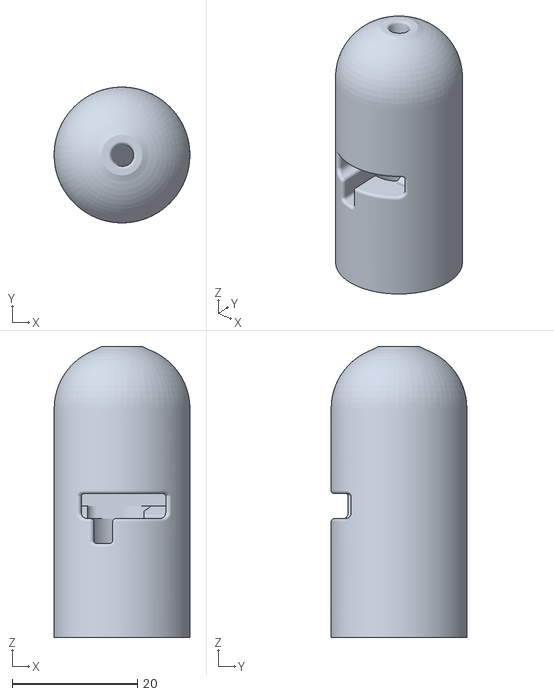
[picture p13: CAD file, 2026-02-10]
0_CAD/Device_V6-3-Core.stl
21.7 x 21.7 x 46.5

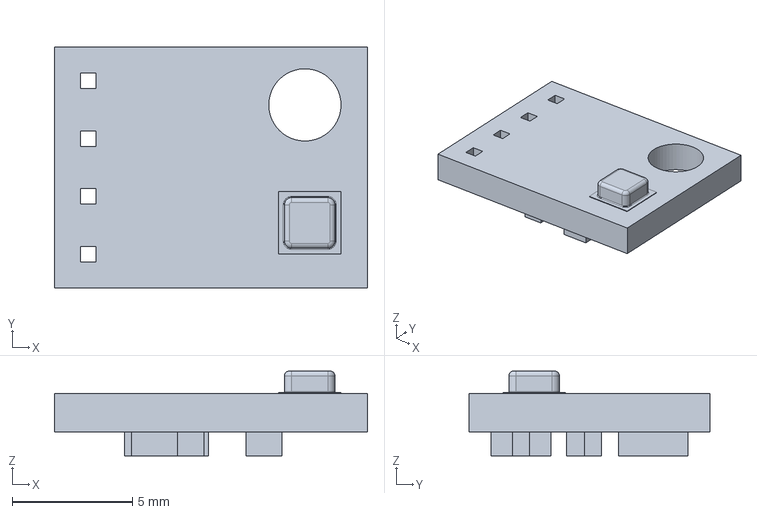
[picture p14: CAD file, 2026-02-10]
0_CAD/BME280-5V-raw.FCStd
13.0 x 10.0 x 3.53 mm

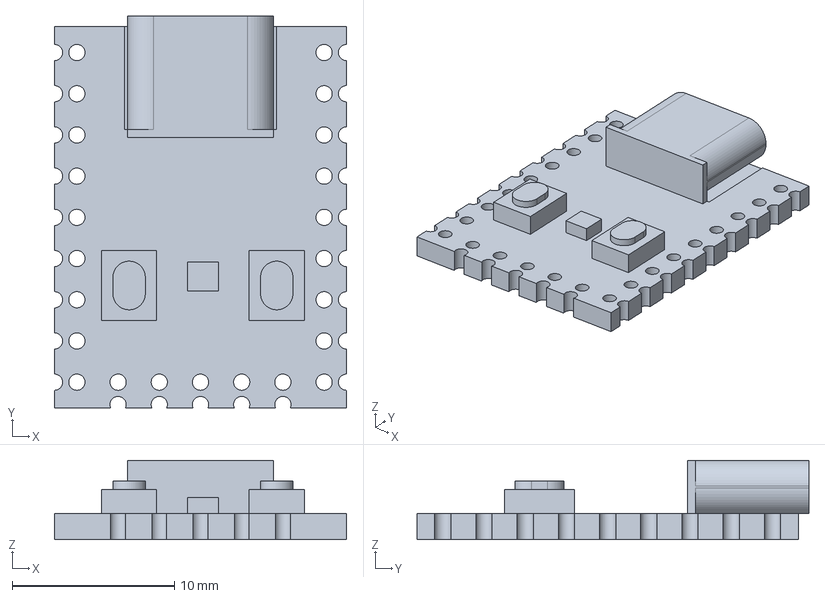
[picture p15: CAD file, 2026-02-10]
0_CAD/RP2350-Zero_mini.FCStd
18.0 x 24.2 x 4.88 mm

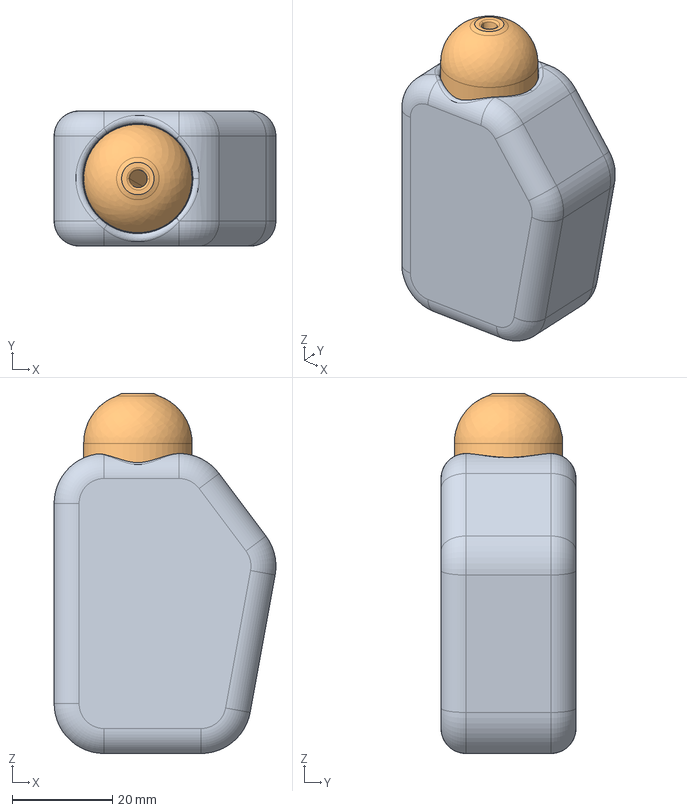
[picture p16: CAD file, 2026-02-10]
0_CAD/Device_V6.FCStd
44.4 x 27.0 x 72.0 mm
Main-body
Core
RP2350-Zero-mini
BME280-5V

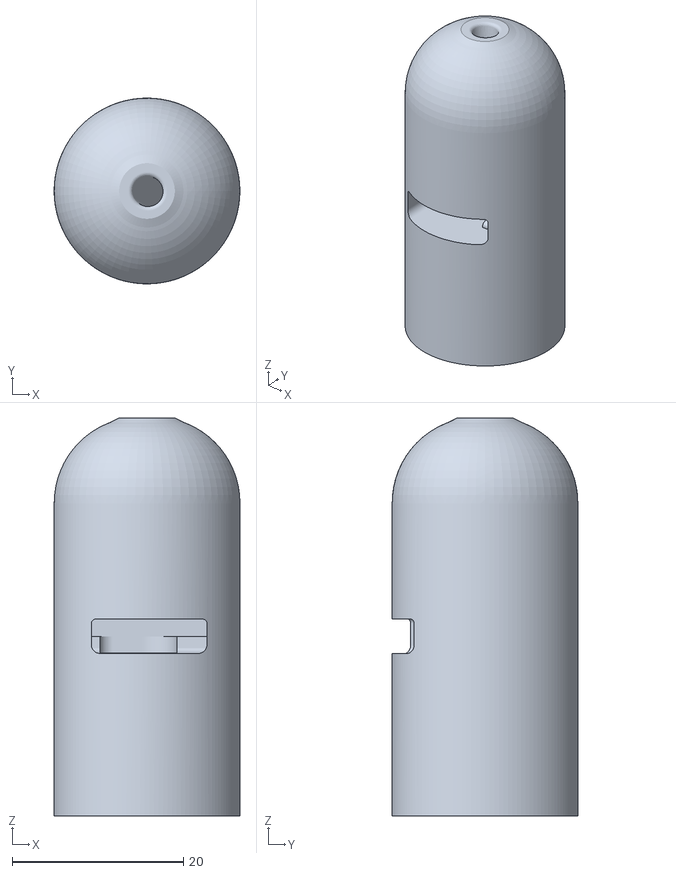
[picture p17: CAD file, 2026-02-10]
0_CAD/Device_V6-2-Core.stl
21.7 x 21.7 x 46.5

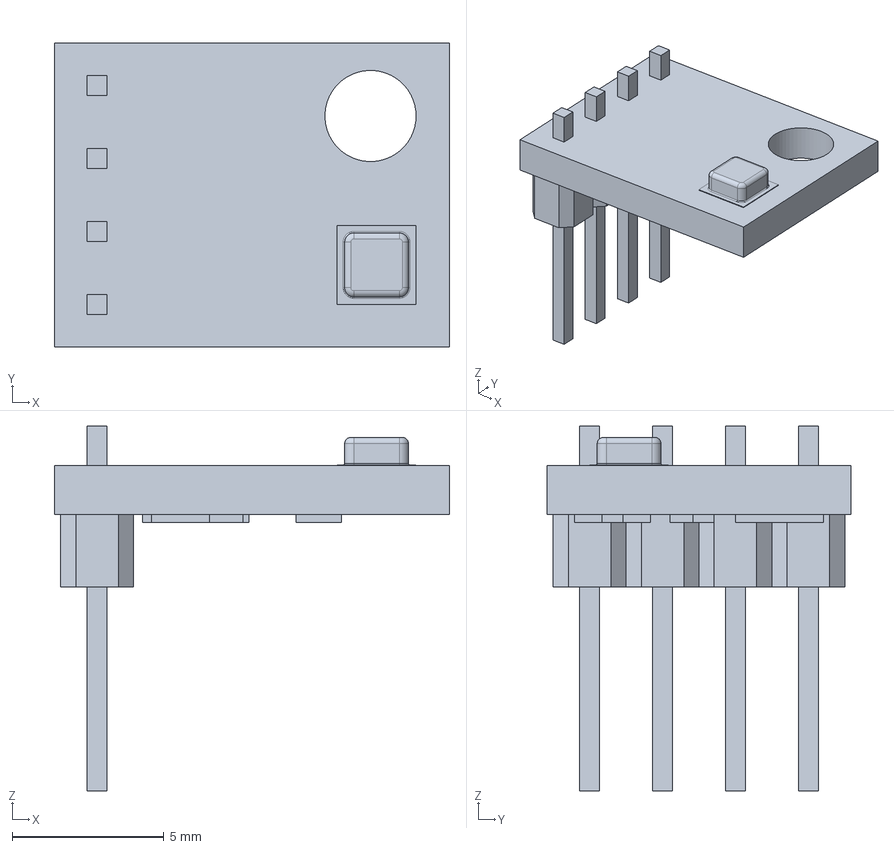
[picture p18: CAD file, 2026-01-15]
0_CAD/BME280-5V.FCStd
13.0 x 10.0 x 12.0 mm

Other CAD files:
0_CAD/Device_V7-2-Main-body.stl
0_CAD/BME280-5V-raw-BME280-5V.step
0_CAD/RP2350-Zero_mini-Body.step
0_CAD/Device_V9-Main-body.stl
0_CAD/Device_V8-Main-body.stl
0_CAD/Device_V7-Main-body.stl
0_CAD/Device_V4.FCStd
0_CAD/Device_V5.FCStd
0_CAD/Device_V8-Core-sub.stl

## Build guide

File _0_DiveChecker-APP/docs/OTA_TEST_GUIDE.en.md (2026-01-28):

# DiveChecker OTA Firmware Update Test Guide

## Test Environment Setup

### 1. Key Generation (One-time)
```bash
cd 0_Pico2-Firmware/Divechecker
./generate_keys.sh
```
- `keys/divechecker_private.pem`: Private key for firmware signing
- `keys/divechecker_public.pem`: Public key for verification
- `keys/ecdsa_private_keys.h`: Key header for MCU

### 2. Firmware Build
```bash
cd 0_Pico2-Firmware/Divechecker
mkdir -p build && cd build
cmake -DPICO_SDK_PATH=$HOME/pico/pico-sdk ..
make -j4
```
Result: `Divechecker.uf2`

### 3. Firmware Signing
```bash
cd 0_Pico2-Firmware/Divechecker
./sign_firmware.sh build/Divechecker.uf2
```
Result: `build/Divechecker_signed.bin`

---

## App Testing

### 1. Regenerate l10n
```bash
cd _0_DiveChecker-APP
flutter gen-l10n
```

### 2. Run App
```bash
flutter run -d linux  # or macos, windows
```

### 3. Firmware Verification Tests

#### Test Case 1: Properly Signed Firmware
1. Copy `Divechecker_signed.bin` to Downloads folder
2. Settings → My Device → DiveChecker → Firmware Update
3. Select file → ✓ **Signature Valid** should display

#### Test Case 2: Invalid File
1. Select any `.bin` file
2. ✗ **Invalid magic header** error should appear

#### Test Case 3: Corrupted Signature
```bash
# Corrupt the file
dd if=/dev/urandom of=corrupted.bin bs=1 count=100
cat build/Divechecker_signed.bin >> corrupted.bin
```
- ✗ **Signature verification failed** should appear

#### Test Case 4: Firmware Signed with Different Key
```bash
# Generate new key and sign
openssl ecparam -genkey -name prime256v1 -noout -out fake_key.pem
# ... Firmware signed with this key will fail verification
```

---

## BOOTSEL Testing

### Test Procedure
1. With device connected, go to Settings → My Device → DiveChecker
2. Select "BOOTSEL Mode"
3. Confirm in dialog by selecting "Reboot"
4. Verify results:
   - USB connection disconnected
   - `RPI-RP2` drive appears
   - `.uf2` file can be copied

### Recovery Test
After installing corrupted firmware:
1. Disconnect device, hold BOOTSEL button while reconnecting
2. Copy working firmware to `RPI-RP2` drive

---

## Verification Checklist

### Security
- [x] ECDSA P-256 signature verification
- [x] SHA-256 hash calculation
- [x] DER signature format parsing
- [x] Reject invalid keys
- [x] Reject corrupted files
- [x] Detect size mismatch

### UI/UX
- [x] File list display
- [x] Verification result display (success/failure)
- [x] File info display (size, hash)
- [x] Version info parsing (when available)
- [x] BOOTSEL reboot confirmation dialog

### Error Handling
- [x] Handle missing files
- [x] Handle file read errors
- [x] Handle network errors (for future GitHub integration)
- [ ] Handle timeouts (large files)

---

## Limitations and Future Improvements

### Current Limitations
1. **Manual copy required**: After BOOTSEL, `.uf2` file must be copied manually
2. **Downgrade possible**: Only warning shown after version comparison
3. **Single device only**: Multiple simultaneous device connections not supported

### Planned Improvements
1. Automatic firmware download from GitHub Releases
2. Option to allow only upgrades after version comparison
3. Automatic USB Mass Storage copy (platform-specific)
4. Update rollback support

---

## Troubleshooting

### Problem: Signature verification always fails
**Cause**: App's public key differs from private key used for signing
**Solution**: Re-run `generate_keys.sh` and rebuild both app and firmware

### Problem: BOOTSEL command unresponsive
**Cause**: MIDI connection lost or firmware doesn't support command
**Solution**: Reconnect device and retry, verify firmware version

### Problem: RPI-RP2 drive not visible
**Cause**: USB connection issue or already flashed
**Solution**: Replace USB cable, reconnect device power

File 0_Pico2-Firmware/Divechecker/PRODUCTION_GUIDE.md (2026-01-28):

# DiveChecker Production Deployment Guide

## 🔐 보안 키 관리 및 OTP 프로그래밍

### 개요

DiveChecker는 ECDSA P-256 비대칭 암호화를 사용하여 기기 인증을 수행합니다.

| 모드 | 키 저장 위치 | 용도 |
|---|---|---|
| Development | Flash (header file) | 개발/테스트 |
| Production | OTP (One-Time Programmable) | 양산 제품 |

### ⚠️ 중요: OTP는 한번 쓰면 변경 불가!

OTP(One-Time Programmable) 메모리는 물리적 퓨즈 기반으로, 한번 프로그래밍되면 **영구적으로 변경할 수 없습니다**.

---

## 1단계: 키 생성 (최초 1회)

```bash
cd 0_Pico2-Firmware/Divechecker
chmod +x generate_keys.sh
./generate_keys.sh
```

생성되는 파일:
- `keys/divechecker_private.pem` - 개인키 (PEM)
- `keys/divechecker_public.pem` - 공개키 (PEM)
- `keys/ecdsa_private_keys.h` - MCU용 (C header)
- `keys/ecdsa_public_key.dart` - App용 (Dart)

**⚠️ 키 백업 필수!** USB 드라이브나 안전한 위치에 보관하세요.

---

## 2단계: 개발 모드 테스트

### 2-1. MCU 빌드 (Flash 키 사용)

```bash
mkdir build && cd build
cmake ..
make
```

### 2-2. Flutter 앱에 공개키 복사

```bash
cp keys/ecdsa_public_key.dart ../_0_DiveChecker-APP/lib/security/
```

### 2-3. 테스트

1. 펌웨어 플래시
2. 앱 빌드 및 설치
3. 기기 연결 → 인증 성공 확인
4. USB 콘솔 로그 확인: `Device authentication: SUCCESS ✓`

---

## 3단계: OTP 프로그래밍 (Production)

### 사전 체크리스트

- [ ] 키 백업 완료
- [ ] 개발 모드에서 인증 테스트 성공
- [ ] Flutter 앱에서 인증 동작 확인
- [ ] **이 기기에 대해 OTP 프로그래밍이 처음임을 확인**

### 3-1. OTP 프로그래밍 실행

```bash
chmod +x program_otp_keys.sh
./program_otp_keys.sh
```

스크립트가 다음을 수행:
1. 키 파일 검증
2. picotool로 기기 확인 (BOOTSEL 모드)
3. 2단계 확인 후 OTP 쓰기

### 3-2. Production 펌웨어 빌드

`Divechecker.c`에서 주석 해제:
```c
// Uncomment for production builds with OTP keys:
#define USE_OTP_KEYS
```

재빌드:
```bash
cd build
make clean
make
```

### 3-3. 최종 테스트

1. Production 펌웨어 플래시
2. 앱에서 인증 테스트
3. USB 콘솔 로그 확인: `INFO:Keys loaded from OTP`

---

## 4단계: 펌웨어 업데이트 (Secure OTA)

### 서명된 펌웨어 생성

```bash
chmod +x sign_firmware.sh
./sign_firmware.sh build/Divechecker.uf2
```

출력:
- `build/Divechecker_signed.bin` - 서명된 펌웨어
- `build/Divechecker.sig` - 서명 파일

### OTA 업데이트 프로세스

1. 서명된 펌웨어를 앱으로 전송
2. MCU가 서명 검증
3. 검증 성공 시에만 업데이트 적용

---

## 보안 고려사항

### 키 보안

| 항목 | 권장 사항 |
|---|---|
| 개인키 백업 | 오프라인 저장 (USB, 금고) |
| 개인키 삭제 | OTP 프로그래밍 후 PC에서 삭제 |
| 공개키 | 앱에 포함 (노출되어도 안전) |
| Git | keys/ 폴더 절대 커밋 금지 |

### OTP 읽기 보호

추가 보안을 위해 OTP 읽기 보호 설정 가능:
```bash
picotool otp lock OTP_PRIVATE_KEY_ROW
```

⚠️ 읽기 보호 후에는 picotool로도 키를 읽을 수 없음!

---

## 문제 해결

### OTP 프로그래밍 실패

| 오류 | 해결 방법 |
|---|---|
| "No device found" | BOOTSEL 모드로 진입 |
| "picotool not found" | picotool 설치 확인 |
| "Keys not found" | generate_keys.sh 먼저 실행 |

### 인증 실패

| USB 콘솔 출력 | 원인 | 해결 |
|---|---|---|
| `WARN:ECDSA keys not configured` | 플레이스홀더 키 | 키 생성/복사 |
| `WARN:OTP keys not programmed` | OTP 미프로그래밍 | OTP 프로그래밍 |
| `AUTH_ERR:Sign failed` | mbedtls 오류 | 키 손상 확인 |

---

## 파일 구조

```
0_Pico2-Firmware/Divechecker/
├── Divechecker.c           # 메인 펌웨어
├── otp_keys.h              # OTP 키 읽기 헤더
├── generate_keys.sh        # 키 생성 스크립트
├── program_otp_keys.sh     # OTP 프로그래밍 스크립트
├── sign_firmware.sh        # 펌웨어 서명 스크립트
└── keys/                   # ⚠️ GITIGNORE!
    ├── divechecker_private.pem
    ├── divechecker_public.pem
    ├── ecdsa_private_keys.h
    └── ecdsa_public_key.dart
```

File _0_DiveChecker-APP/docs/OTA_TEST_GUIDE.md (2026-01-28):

# DiveChecker OTA 펌웨어 업데이트 테스트 가이드

[🇺🇸 English](OTA_TEST_GUIDE.en.md)

## 테스트 환경 준비

### 1. 키 생성 (최초 1회)
```bash
cd 0_Pico2-Firmware/Divechecker
./generate_keys.sh
```
- `keys/divechecker_private.pem`: 펌웨어 서명용 개인키
- `keys/divechecker_public.pem`: 검증용 공개키
- `keys/ecdsa_private_keys.h`: MCU용 키 헤더

### 2. 펌웨어 빌드
```bash
cd 0_Pico2-Firmware/Divechecker
mkdir -p build && cd build
cmake -DPICO_SDK_PATH=$HOME/pico/pico-sdk ..
make -j4
```
결과: `Divechecker.uf2`

### 3. 펌웨어 서명
```bash
cd 0_Pico2-Firmware/Divechecker
./sign_firmware.sh build/Divechecker.uf2
```
결과: `build/Divechecker_signed.bin`

---

## 앱 테스트

### 1. l10n 재생성
```bash
cd _0_DiveChecker-APP
flutter gen-l10n
```

### 2. 앱 실행
```bash
flutter run -d linux  # 또는 macos, windows
```

### 3. 펌웨어 검증 테스트

#### 테스트 케이스 1: 정상 서명된 펌웨어
1. `Divechecker_signed.bin`을 Downloads 폴더에 복사
2. 설정 → 내 기기 → DiveChecker → 펌웨어 업데이트
3. 파일 선택 → ✓ **Signature Valid** 표시 확인

#### 테스트 케이스 2: 잘못된 파일
1. 임의의 `.bin` 파일 선택
2. ✗ **Invalid magic header** 에러 확인

#### 테스트 케이스 3: 손상된 서명
```bash
# 파일 일부 변조
dd if=/dev/urandom of=corrupted.bin bs=1 count=100
cat build/Divechecker_signed.bin >> corrupted.bin
```
- ✗ **Signature verification failed** 확인

#### 테스트 케이스 4: 다른 키로 서명된 펌웨어
```bash
# 새 키 생성 후 서명
openssl ecparam -genkey -name prime256v1 -noout -out fake_key.pem
# ... 이 키로 서명된 펌웨어는 검증 실패
```

---

## BOOTSEL 테스트

### 테스트 절차
1. 기기 연결 상태에서 설정 → 내 기기 → DiveChecker
2. "BOOTSEL 모드" 선택
3. 확인 다이얼로그에서 "재부팅" 선택
4. 결과 확인:
   - USB 연결 해제됨
   - `RPI-RP2` 드라이브 나타남
   - `.uf2` 파일 복사 가능

### 복구 테스트
잘못된 펌웨어 설치 후 복구:
1. 기기 전원 끈 상태에서 BOOTSEL 버튼 누르고 연결
2. `RPI-RP2` 드라이브에 정상 펌웨어 복사

---

## 검증 항목 체크리스트

### 보안
- [x] ECDSA P-256 서명 검증
- [x] SHA-256 해시 계산
- [x] DER 서명 포맷 파싱
- [x] 잘못된 키 거부
- [x] 손상된 파일 거부
- [x] 크기 불일치 감지

### UI/UX
- [x] 파일 목록 표시
- [x] 검증 결과 표시 (성공/실패)
- [x] 파일 정보 표시 (크기, 해시)
- [x] 버전 정보 파싱 (가능한 경우)
- [x] BOOTSEL 재부팅 확인 다이얼로그

### 에러 처리
- [x] 파일 없음 처리
- [x] 파일 읽기 오류 처리
- [x] 네트워크 오류 처리 (향후 GitHub 연동 시)
- [ ] 타임아웃 처리 (대용량 파일)

---

## 제한사항 및 향후 개선

### 현재 제한사항
1. **수동 복사 필요**: BOOTSEL 후 `.uf2` 파일을 직접 복사해야 함
2. **다운그레이드 가능**: 버전 비교 후 경고만 표시
3. **단일 기기만 지원**: 여러 기기 동시 연결 미지원

### 향후 개선 예정
1. GitHub Releases에서 펌웨어 자동 다운로드
2. 펌웨어 버전 비교 및 업그레이드만 허용 옵션
3. USB Mass Storage 자동 복사 (플랫폼별)
4. 업데이트 롤백 지원

---

## 트러블슈팅

### 문제: 서명 검증 항상 실패
**원인**: 앱의 공개키와 서명에 사용된 개인키가 다름
**해결**: `generate_keys.sh` 재실행 후 앱/펌웨어 모두 재빌드

### 문제: BOOTSEL 명령 무응답
**원인**: MIDI 연결 끊김 또는 펌웨어 미지원
**해결**: 기기 재연결 후 재시도, 펌웨어 버전 확인

### 문제: RPI-RP2 드라이브 안 보임
**원인**: USB 연결 문제 또는 이미 플래싱 완료
**해결**: USB 케이블 교체, 기기 전원 재연결

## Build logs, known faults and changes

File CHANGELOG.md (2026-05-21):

# Changelog

**English** | [한국어](docs/CHANGELOG.ko.md)

All notable changes to this project will be documented in this file.

The format is based on [Keep a Changelog](https://keepachangelog.com/en/1.1.0/),
and this project aims to follow [Semantic Versioning](https://semver.org/spec/v2.0.0.html).

## [Unreleased]

<!--
Template for each new version section — copy this stanza when cutting a release.
Keep `### Highlights` at the very top: it is the first thing users see on the
GitHub release page. Release notes scripts (if any) take the section verbatim.

### Highlights

**One-sentence headline.** Optional 1-2 sentence elaboration if needed.

- Most important user-visible change (one line, scannable)
- Second most important change
- (3-6 bullets max, no prose blocks)

### Added
### Changed
### Fixed
-->

## [8.6.1] — 2026-05-21

### Highlights

**Windows-only "정품인증 실패" auth failure fix.** The Windows desktop build was shipping without a MIDI backend registered, so the ECDSA challenge nonce never reached the device and authentication silently timed out. Linux, macOS, Android, iOS, and Web builds were unaffected.

- Forces `flutter_midi_command_windows` registration via a direct dependency.
- Bumps `flutter_midi_command` to 0.5.4 (MR #144 Windows backend update).

### Fixed

- **Windows: ECDSA device authentication failed with "정품인증 실패" on every connect.** `windows/flutter/generated_plugins.cmake` did not list `flutter_midi_command_windows`, so `_midiHandler.sendSysEx()` was a no-op on Windows: the auth challenge nonce never went out, the device never responded, and `_authenticateDevice()` hit its 3-second timeout and flipped `_isAuthenticated = false`. Linux registered `flutter_midi_command_linux` and macOS imported `flutter_midi_command` correctly. Federated endorsement of the Windows impl in `flutter_midi_command` 0.5.3 was unreliable. Fix: add `flutter_midi_command_windows: ^0.3.0` as a direct dependency, bump `flutter_midi_command` to `^0.5.4`, and inject `flutter_midi_command_windows` into the Windows plugin list. After upgrade, run `flutter clean && flutter pub get && flutter build windows --release`.

## [8.1.0] — 2026-03-19

### Added
- macOS App Store Connect auto-upload in CI/CD pipeline
- macOS ExportOptions.plist for signed distribution

### Changed
- Optimized chart rendering with single-pass min/max calculation
- Replaced Consumer with Selector in measurement screen
- Aligned all docs and app constants with firmware source of truth (100Hz, 300-1250 hPa, 30s keepalive, 256-byte SysEx)
- Protocol table updated to SysEx hex command table
- Firmware tree updated to actual file names
- Moved README.ko.md to docs/ per bilingual convention

### Fixed
- Mounted check and error handling in graph notes loading
- StreamController cleanup in MidiProvider shutdown
- Reset MIDI data listener on device switch to prevent staircase graph
- CAD README: BMP280-5V corrected to BME280-5V
- App README: Dart SDK 3.0+ corrected to 3.10+, removed nonexistent integration_test/
- Graph detail page maxY clamp raised from 100 to 200

### Security
- Hardened .gitignore: added .p12, .p8, .env, provisioning profile rules
- Removed tmp-igbkp/ from git tracking

## [8.0.1] — 2026-03-19

### Fixed
- Reset MIDI data listener on device switch to prevent staircase graph

## [8.0.0] — 2026-03-18 (RTM 8.0)

### Added
- GitHub standard files: SECURITY, CONTRIBUTING, CODE_OF_CONDUCT, CHANGELOG (en+ko)
- GitHub templates: PR template, bug report, feature request issue templates
- Bilingual documentation structure (docs/ directory with Korean translations)

### Fixed
- CONTRIBUTING.md link in root README now points to correct location

## [7.2.0] — 2026-03-12 (RTM 7.2)

### Added
- Multi-language support: Japanese (ja), Simplified Chinese (zh), Traditional Chinese (zh_TW)
- Locale provider enhancement with country code support and SharedPreferences persistence

### Fixed
- Graph note pressure display: fixed timestamp used as array index, now uses nearest-point lookup
- Statistics duration calculation: fixed 10x incorrect value
- Division by zero guards for skewness/kurtosis, trend graph slope, and change rate
- Peak analyzer RangeError when `checkStart` exceeds `lastIdx`
- GraphNote type safety with explicit casts in `fromMap()` factory
- SessionRepository dispose guard to prevent `notifyListeners()` after dispose

### Security
- Firmware `strcpy` → `strncpy`: replaced 3 unsafe calls with bounded copies
- ECDSA error counter increment on signature failure for diagnostics

### Changed
- Replaced remaining hardcoded strings with l10n in measurement, history, and settings screens
- Updated web branding (index.html, manifest.json)

## [7.1.1] — 2026-03-11

### Fixed
- Minor stability improvements and bug fixes

## [7.1.0] — 2026-03-10

### Added
- Session delete button in history screen
- Fullscreen chart view for real-time measurement

## [6.0.0] — 2026-03-03 (RTM 6.0)

### Fixed
- Root cause stabilization: firmware Core 1 sampling no longer depends on app connection state
- Reconnect baseline preservation: removed implicit baseline reset on transient reconnect
- Flash lockout recovery guard with I2C grace window
- Keepalive resilience: increased timeout margins, tolerant to transient MIDI stream errors
- Cross-core memory ordering: added `__dmb()` barriers for baseline and lockout flags

## [4.0.0] — 2026-02-26 (RTM 4.0)

### Security
- Backup integrity verification with checksum validation
- Enhanced flash CRC validation with magic field check
- INT32_MIN safe encoding in MIDI SysEx pressure encoding
- Memory barriers (`__dmb()`) for cross-core output rate changes

### Fixed
- Peak analysis time calculation (was using `*0.25` instead of `/1000.0`)
- GraphNote class collision between models and database layer
- USB serial number correctly set from chip unique ID
- LED initialization guard to prevent infinite PIO blocking

### Changed
- Monitor screen: timer-based UI updates (10Hz) instead of per-sample setState
- Peak analyzer: O(1) set lookup replaces O(n) List.contains
- USB enumeration: reduced wait loop from 500ms to 10ms intervals
- SerialProvider removed; all code uses MidiProvider directly
- Linux binary/app ID unified to `kr.createch.divechecker`
- macOS bundle ID unified to `io.kodenet.divechecker`
- Developer attribution updated from KodeNet to Createch (크리에이테크)
- USB manufacturer string updated from `kodenet.io` to `createch.kr`
- Contact emails migrated to createch.kr domain (legal@, contact@, cs-divechecker@)

## [3.0.0] — 2026-02-19 (RTM 3.0)

### Security
- Soft reboot PIN protection
- Persistent PIN lockout surviving device reboot
- Flash CRC32 validation on settings load
- Crypto buffer zeroing after authentication
- Constant-time hex validation against timing attacks

### Added
- Auto-reconnect with exponential backoff (2/4/6s, max 3 attempts)
- Sensor auto-recovery: 5-second periodic retry on BMP280 I2C failure
- Early watchdog: 8s boot timeout, 2s operation timeout
- SysEx timeout parser reset from any state after 500ms
- Dynamic Y-axis auto-scaling for measurement and monitor charts
- Extended measurement range: BMP280 max raised to 1250 hPa

### Fixed
- FIFO handshake bug causing stale status reads
- Concurrent sensor reinit race condition
- mbedTLS context leak before re-initialization
- Measurement disconnect crash during save dialog
- BOOTSEL ALSA crash with safe shutdown sequence

## [1.2.0] — 2026-01

### Changed
- Mobile chart performance: reduced LOD points, added RepaintBoundary, disabled animations
- LOD system simplified: consolidated to single `_lodData`
- Removed ESP32 firmware; project now Pico RP2350 only

## [1.1.0] — 2026-01-08

### Added
- USB MIDI SysEx communication protocol
- ECDSA P-256 device authentication
- Viewport-based chart rendering with LTTB-like downsampling
- Pinch-to-zoom and pan gestures
- Incremental statistics (O(1) per update)

## [1.0.0] — 2025-12-17

### Added
- Initial release of DiveChecker
- Real-time pressure monitoring with 100Hz internal sampling
- Interactive pressure graphs with zoom and pan
- SQLite database for local data persistence
- USB MIDI device connection support
- Session history with analytics
- Cross-platform support (Android, iOS, Linux, Windows, macOS)

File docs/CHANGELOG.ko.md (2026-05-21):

# 변경 이력

[English](../CHANGELOG.md) | **한국어**

이 프로젝트의 주요 변경 사항은 이 문서에 기록됩니다.

형식은 [Keep a Changelog](https://keepachangelog.com/en/1.1.0/)를 기반으로 하며,
버전 정책은 [Semantic Versioning](https://semver.org/lang/ko/)을 지향합니다.

## [Unreleased]

<!--
각 새 버전 섹션 템플릿 — 릴리스 자를 때 이 stanza를 복사하세요.
`### Highlights`는 항상 최상단에 두세요. GitHub 릴리스 페이지에서 사용자가
가장 먼저 보는 영역이며, 릴리스 노트 스크립트가 있다면 이 섹션 전체를
그대로 가져갑니다.

### Highlights

**한 문장 헤드라인.** 필요 시 1-2 문장 부연 설명.

- 가장 중요한 사용자 가시 변경 (한 줄, 스캔 가능)
- 두 번째로 중요한 변경
- (최대 3-6 bullets, 산문 블록 금지)

### 추가됨
### 변경됨
### 수정됨
-->

## [8.6.1] — 2026-05-21

### Highlights

**Windows 전용 "정품인증 실패" 오류 수정.** Windows 데스크탑 빌드에 MIDI 백엔드가 등록되어 있지 않아 ECDSA challenge nonce가 디바이스에 전달되지 않고 인증이 timeout되던 문제. Linux / macOS / Android / iOS / Web 빌드는 영향 없음.

- `flutter_midi_command_windows`를 직접 의존성으로 추가해 강제 등록.
- `flutter_midi_command` 0.5.4로 bump (MR #144 Windows 백엔드 업데이트).

### 수정됨

- **Windows: 연결할 때마다 ECDSA 디바이스 인증이 "정품인증 실패"로 끝나던 문제.** `windows/flutter/generated_plugins.cmake`에 `flutter_midi_command_windows`가 누락되어 Windows에서 `_midiHandler.sendSysEx()`가 무동작이었고, auth challenge nonce가 송신되지 않아 디바이스 응답도 없었음. 결국 `_authenticateDevice()`가 3초 timeout에 걸려 `_isAuthenticated = false`로 떨어졌음. Linux는 `flutter_midi_command_linux`를 등록하고 macOS는 `flutter_midi_command`를 import해서 정상이었음. `flutter_midi_command` 0.5.3의 Windows impl federated endorsement가 불안정해서 발생. 수정: `flutter_midi_command_windows: ^0.3.0`을 직접 의존성으로 추가, `flutter_midi_command`를 `^0.5.4`로 bump, Windows plugin 목록에 `flutter_midi_command_windows`를 inject. 업그레이드 후 `flutter clean && flutter pub get && flutter build windows --release` 실행.

## [8.1.0] — 2026-03-19

### 추가됨
- macOS App Store Connect CI/CD 자동 업로드
- macOS ExportOptions.plist (서명 배포용)

### 변경됨
- 차트 렌더링 최적화: 단일 패스 min/max 계산
- 측정 화면 Consumer → Selector 교체 (불필요한 리빌드 감소)
- 전체 문서 및 앱 상수를 펌웨어 소스에 맞춤 (100Hz, 300-1250 hPa, 30초 타임아웃, 256바이트 SysEx)
- 프로토콜 테이블: 레거시 텍스트 → SysEx hex 명령 테이블
- 펌웨어 트리: 기능 설명 → 실제 파일명
- README.ko.md를 docs/로 이동 (이중언어 규칙)

### 수정됨
- 그래프 노트 로딩에 mounted 체크 및 에러 핸들링 추가
- MidiProvider shutdown 시 StreamController 정리
- 디바이스 전환 시 MIDI 데이터 리스너 리셋 (계단식 그래프 방지)
- CAD README: BMP280-5V → BME280-5V 수정
- 앱 README: Dart SDK 3.0+ → 3.10+, 존재하지 않는 integration_test/ 제거
- 그래프 상세 페이지 maxY 클램프 100 → 200

### 보안
- .gitignore 강화: .p12, .p8, .env, 프로비저닝 프로파일 규칙 추가
- tmp-igbkp/ git 추적 제거

## [8.0.1] — 2026-03-19

### 수정됨
- 디바이스 전환 시 MIDI 데이터 리스너 리셋 (계단식 그래프 방지)

## [8.0.0] — 2026-03-18 (RTM 8.0)

### 추가됨
- GitHub 표준 파일: SECURITY, CONTRIBUTING, CODE_OF_CONDUCT, CHANGELOG (영어+한국어)
- GitHub 템플릿: PR 템플릿, 버그 리포트, 기능 요청 이슈 템플릿
- 이중언어 문서 구조 (docs/ 디렉토리 한국어 번역)

### 수정됨
- 루트 README의 CONTRIBUTING.md 링크 수정

## [7.2.0] — 2026-03-12 (RTM 7.2)

### 추가됨
- 다국어 지원: 일본어 (ja), 중국어 간체 (zh), 중국어 번체 (zh_TW)
- 로케일 프로바이더 개선: 국가 코드 지원 및 SharedPreferences 영속화

### 수정됨
- 그래프 노트 압력 표시: 타임스탬프를 배열 인덱스로 사용하던 버그 → 최근접 포인트 탐색으로 수정
- 통계 측정 시간: 10배 오차 수정
- 왜도/첨도, 추세 그래프 기울기, 변화율의 0 나누기 방지
- 피크 분석기 `checkStart`가 `lastIdx` 초과 시 RangeError 수정
- GraphNote `fromMap()` 팩토리 타입 안전성 개선
- SessionRepository dispose 후 `notifyListeners()` 방지 가드

### 보안
- 펌웨어 `strcpy` → `strncpy`: 3개 비안전 호출을 바운디드 복사로 교체
- ECDSA 서명 실패 시 에러 카운터 증분 (진단용)

### 변경됨
- 측정/히스토리/설정 화면 하드코딩 문자열 → l10n 전환
- 웹 브랜딩 업데이트 (index.html, manifest.json)

## [7.1.1] — 2026-03-11

### 수정됨
- 마이너 안정성 개선 및 버그 수정

## [7.1.0] — 2026-03-10

### 추가됨
- 히스토리 화면에 세션 삭제 버튼
- 실시간 측정 전체화면 차트 뷰

## [6.0.0] — 2026-03-03 (RTM 6.0)

### 수정됨
- 근본 원인 안정화: 펌웨어 Core 1 샘플링이 앱 연결 상태에 의존하지 않도록 수정
- 재연결 기준점 보존: 일시적 재연결 시 암묵적 기준점 리셋 제거
- 플래시 잠금 해제 후 I2C 유예 창 추가
- 킵얼라이브 복원력: 타임아웃 마진 증가, 일시적 MIDI 스트림 에러 허용
- 크로스코어 메모리 순서: 기준점 및 잠금 플래그에 `__dmb()` 배리어 추가

## [4.0.0] — 2026-02-26 (RTM 4.0)

### 보안
- 백업 무결성 검증 (체크섬 검증)
- 플래시 CRC 검증 강화 (매직 필드 확인)
- MIDI SysEx 압력 인코딩 INT32_MIN 안전 처리
- 크로스코어 출력 속도 변경에 메모리 배리어 추가

### 수정됨
- 피크 분석 시간 계산 (`*0.25` → `/1000.0`)
- GraphNote 클래스 충돌 (모델/DB 레이어 간)
- USB 시리얼 번호를 칩 ID에서 올바르게 설정
- LED 초기화 실패 시 무한 PIO 블로킹 방지

### 변경됨
- 모니터 화면: 타이머 기반 UI 업데이트 (10Hz)
- 피크 분석기: O(1) 집합 탐색으로 개선
- USB 열거: 대기 루프 500ms → 10ms
- SerialProvider 제거; MidiProvider 직접 사용
- Linux 앱 ID를 `kr.createch.divechecker`로 변경
- macOS 번들 ID `io.kodenet.divechecker` 유지
- 개발사 표기를 KodeNet에서 크리에이테크 (Createch)로 변경
- USB 제조사명을 `kodenet.io`에서 `createch.kr`로 변경
- 연락처 이메일을 createch.kr 도메인으로 이관 (legal@, contact@, cs-divechecker@)

## [3.0.0] — 2026-02-19 (RTM 3.0)

### 보안
- 소프트 리부트 PIN 보호
- PIN 잠금 영속화 (재부팅 후에도 유지)
- 설정 로드 시 플래시 CRC32 검증
- 인증 후 암호 버퍼 제로화
- 타이밍 공격 방지 상수 시간 hex 검증

### 추가됨
- 자동 재연결: 지수 백오프 (2/4/6초, 최대 3회)
- 센서 자동 복구: BMP280 I2C 실패 시 5초 주기 재시도
- 조기 워치독: 부팅 8초, 운영 2초 타임아웃
- SysEx 타임아웃: 500ms 후 모든 상태에서 파서 리셋
- 측정/모니터 차트 동적 Y축 자동 스케일링
- BMP280 최대 측정 범위 1250 hPa로 확장

### 수정됨
- FIFO 핸드셰이크 버그로 인한 스테일 상태 읽기
- 동시 센서 재초기화 레이스 컨디션
- mbedTLS 컨텍스트 누수
- 저장 대화상자 중 연결 끊김 크래시
- BOOTSEL 안전 종료 시퀀스 (ALSA 크래시 수정)

## [1.2.0] — 2026-01

### 변경됨
- 모바일 차트 성능: LOD 포인트 축소, RepaintBoundary 추가, 애니메이션 비활성화
- LOD 시스템 단순화: 단일 `_lodData`로 통합
- ESP32 펌웨어 제거; Pico RP2350 전용으로 전환

## [1.1.0] — 2026-01-08

### 추가됨
- USB MIDI SysEx 통신 프로토콜
- ECDSA P-256 디바이스 인증
- 뷰포트 기반 차트 렌더링 (LTTB 유사 다운샘플링)
- 핀치 줌 및 팬 제스처
- 증분 통계 (업데이트당 O(1))

## [1.0.0] — 2025-12-17

### 추가됨
- DiveChecker 최초 릴리스
- 100Hz 내부 샘플링 실시간 압력 모니터링
- 줌/팬 지원 인터랙티브 압력 그래프
- SQLite 로컬 데이터 영속화
- USB MIDI 디바이스 연결 지원
- 세션 히스토리 및 분석
- 크로스플랫폼 지원 (Android, iOS, Linux, Windows, macOS)

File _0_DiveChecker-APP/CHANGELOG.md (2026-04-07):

# Changelog

All notable changes to DiveChecker will be documented in this file.

The format is based on [Keep a Changelog](https://keepachangelog.com/en/1.0.0/),
and this project adheres to [Semantic Versioning](https://semver.org/spec/v2.0.0.html).

## [Unreleased]

---

## [8.1.0] - 2026-03-19

### Added
- macOS App Store Connect auto-upload in CI/CD pipeline
- macOS ExportOptions.plist for signed distribution

### Changed
- Optimized chart rendering with single-pass min/max calculation
- Replaced Consumer with Selector in measurement screen for reduced rebuilds
- Aligned all docs and app constants with firmware source of truth (100Hz, 300-1250 hPa, 30s timeout, 256-byte SysEx buffer)
- Renamed MeasurementConfig.minPressure/maxPressure to sensorMinPressure/sensorMaxPressure (300/1250 hPa)
- Graph detail page maxY clamp raised from 100 to 200

### Fixed
- Added mounted check and error handling in graph notes loading
- StreamController cleanup in MidiProvider shutdown
- Reset MIDI data listener on device switch to prevent staircase graph

### Security
- Hardened .gitignore: added .p12, .p8, .env, provisioning profile rules
- Removed tmp-igbkp/ from git tracking

---

## [8.0.1] - 2026-03-19

### Fixed
- Reset MIDI data listener on device switch to prevent staircase graph pattern
- Properly disconnect previous device before connecting a new one

---

## [8.0.0] - 2026-03-18 (RTM 8.0)

### Added
- GitHub standard files: SECURITY, CONTRIBUTING, CODE_OF_CONDUCT, CHANGELOG (en+ko)
- GitHub templates: PR template, bug report, feature request issue templates
- Bilingual documentation structure (docs/ directory)

### Fixed
- CONTRIBUTING.md link corrected in root README

---

## [7.2.0] - 2026-03-12 (RTM 7.2)

### Added
- **Multi-language Support (5 Languages)** - Added Japanese (ja), Simplified Chinese (zh), Traditional Chinese (zh_TW) alongside existing English and Korean
- **Locale Provider Enhancement** - Country code support for zh_TW locale with proper SharedPreferences persistence

### Fixed
- **Graph Note Pressure Display** - Fixed critical bug where `note.x` (millisecond timestamp) was incorrectly used as array index; now uses nearest-point lookup
- **Statistics Duration Calculation** - Fixed duration showing 10x incorrect value (divided by 100 instead of 1000)
- **Division by Zero Guards** - Added stdDev > 0 checks for skewness/kurtosis calculations in statistics dashboard
- **Trend Graph Slope** - Fixed division by zero when all X values are identical in linear regression
- **Trend Graph Change Rate** - Fixed division by zero when first trend line Y value is zero
- **Peak Analyzer RangeError** - Fixed `checkStart` exceeding `lastIdx` causing RangeError in peak detection
- **GraphNote Type Safety** - Added explicit type casts (`as int?`, `as num`, `as String`) in `fromMap()` factory
- **SessionRepository Dispose Guard** - Added `_isDisposed` flag to prevent `notifyListeners()` after dispose

### Security
- **Firmware strcpy -> strncpy** - Replaced 3 unsafe `strcpy()` calls with bounded `strncpy()` in device settings
- **ECDSA Error Counter** - Added error counter increment on signature failure for diagnostics

### Changed
- **Hardcoded Strings -> l10n** - Replaced remaining hardcoded strings in measurement, history, and settings screens
- **Web Branding** - Updated web/index.html and web/manifest.json with DiveChecker branding

---

## [7.1.1] - 2026-03-11 (RTM 7.1.1)

### Fixed
- Minor stability improvements and bug fixes

---

## [7.1.0] - 2026-03-10 (RTM 7.1.0)

### Added
- **Session Delete Button** - Added delete functionality to history screen
- **Fullscreen Chart View** - Added fullscreen chart view for real-time measurement

---

## [6.0.0] - 2026-03-03 (RTM 6.0)

### Fixed
- **Root Cause Stabilization (Sensor Pipeline)** - Firmware Core 1 sampling/filtering no longer depends on app connection state; reconnection no longer cold-starts sensor averaging/IIR pipeline.
- **Reconnect Baseline Preservation** - Removed implicit baseline reset on transient reconnect to prevent sudden 0.0-style pressure re-zero events.
- **Flash Lockout Recovery Guard** - Added post-lockout I2C grace window and raised over-range trigger threshold to avoid false sensor reset loops after settings writes.
- **Keepalive Resilience** - Increased firmware/app timeout margins and made MIDI stream errors tolerant to transient bursts before forcing disconnect.
- **Cross-Core Memory Ordering (Firmware)** - Added missing `__dmb()` barriers for baseline flag write ordering (Core 1) and baseline reset visibility (Core 0 -> Core 1); added pre-write barrier for lockout grace counter to guarantee Core 1 sees the updated value immediately after flash lockout ends.

---

## [4.0.0] - 2026-02-26 (RTM 4.0)

### Security
- **Backup Integrity Verification** - Checksum validation prevents tampered backup restoration
- **Enhanced Flash CRC Validation** - Legacy CRC acceptance now requires magic field verification
- **INT32_MIN Safe Encoding** - Fixed undefined behavior in MIDI SysEx pressure encoding
- **Memory Barrier for Cross-Core** - Proper `__dmb()` barriers for output rate changes

### Fixed
- **Peak Analysis Time Calculation** - Fixed incorrect time display (was using `*0.25` instead of `/1000.0`)
- **GraphNote Class Collision** - Resolved duplicate class names between models and database layer
- **USB Serial Number** - Firmware now correctly sets USB descriptor serial from chip ID
- **LED Init Safety** - Added initialization guard to prevent infinite PIO blocking on init failure

### Changed
- **Monitor Screen Optimization** - Timer-based UI updates (10Hz) instead of per-sample setState (up to 50Hz)
- **Peak Analyzer Set Lookup** - O(1) peak index lookup replaces O(n) List.contains
- **USB Enumeration Speed** - Reduced USB wait loop from 500ms to 10ms intervals
- SerialProvider removed; all code uses MidiProvider directly
- Linux binary/app ID changed to `kr.createch.divechecker`
- macOS bundle ID unified to `io.kodenet.divechecker`
- Developer attribution updated from KodeNet to Createch (크리에이테크)
- Contact emails migrated to createch.kr domain (legal@, contact@, cs-divechecker@)

---

## [3.0.0] - 2026-02-19 (RTM 3.0)

### Security
- Soft reboot PIN protection
- Persistent PIN lockout surviving device reboot
- Flash CRC32 validation on settings load
- Crypto buffer zeroing after authentication
- Constant-time hex validation against timing attacks

### Added
- Auto-reconnect with exponential backoff (2/4/6s, max 3 attempts)
- Sensor auto-recovery: 5-second periodic retry on BMP280 I2C failure
- Early watchdog: 8s boot timeout, 2s operation timeout
- SysEx timeout parser reset from any state after 500ms
- Dynamic Y-axis auto-scaling for measurement and monitor charts
- Extended measurement range: BMP280 max raised to 1250 hPa

### Fixed
- FIFO handshake bug causing stale status reads
- Concurrent sensor reinit race condition
- mbedTLS context leak before re-initialization
- Measurement disconnect crash during save dialog
- BOOTSEL ALSA crash with safe shutdown sequence

---

## [1.2.0] - 2026-01-XX

### Changed
- Mobile chart performance: reduced LOD points, added RepaintBoundary, disabled animations
- LOD system simplified: consolidated to single `_lodData`
- Removed ESP32 firmware; project now Pico RP2350 only

---

## [1.1.0] - 2026-01-08

### Added
- USB MIDI SysEx communication protocol
- ECDSA P-256 device authentication
- Viewport-based chart rendering with LTTB-like downsampling
- Pinch-to-zoom and pan gestures
- Incremental statistics (O(1) per update)

---

## [1.0.0] - 2025-12-17

### Added
- Initial release of DiveChecker
- Real-time pressure monitoring with 100Hz internal sampling
- Interactive pressure graphs with zoom and pan controls
- Note-taking system with time-specific annotations
- SQLite database for local data persistence
- USB MIDI device connection support
- Session history with detailed analytics
- Material Design 3 with GitHub color scheme
- Cross-platform support (Android, iOS, Linux, Windows, macOS)

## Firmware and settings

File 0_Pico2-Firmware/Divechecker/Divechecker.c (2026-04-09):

/**
 * @file Divechecker.c
 * @brief DiveChecker RP2350 (Pico 2) Firmware v6.0.0
 * 
 * @details
 * Dual-core architecture for high-precision pressure monitoring:
 *   - Core 0: USB MIDI communication, command processing
 *   - Core 1: 160Hz BMP280 sensor sampling
 * 
 * Features:
 *   - USB MIDI SysEx protocol for cross-platform support
 *   - Persistent device settings in Flash (name, PIN)
 *   - PIN-protected device configuration
 *   - Unique serial number from chip ID
 *   - WS2812 RGB LED status indication
 * 
 * @author Createch (legal@createch.kr)
 * @copyright Copyright (C) 2025-2026 Createch
 * @license Apache License 2.0
 */

#include <stdio.h>
#include <string.h>
#include <stdbool.h>

#include "pico/stdlib.h"
#include "pico/multicore.h"
#include "pico/util/queue.h"
#include "pico/unique_id.h"
#include "pico/bootrom.h"  // For BOOTSEL reboot

#include "hardware/i2c.h"
#include "hardware/gpio.h"
#include "hardware/pio.h"
#include "hardware/flash.h"
#include "hardware/sync.h"
#include "hardware/watchdog.h"
#include "hardware/clocks.h"
#include "hardware/structs/usb.h"  // Direct USB SIE register access
#include "pico/mutex.h"

// TinyUSB for USB MIDI
#include "tusb.h"
#include "midi_sysex.h"

// mbedtls for ECDSA authentication
#include "mbedtls/ecdsa.h"
#include "mbedtls/sha256.h"
#include "mbedtls/ctr_drbg.h"
#include "mbedtls/ecp.h"

#include "pico/rand.h"
#include <stdlib.h>  // for strtol
#include <math.h>    // for isnan, NAN

#include "ws2812.pio.h"

// ============================================================================
// ECDSA Key Configuration
// ============================================================================
// Build modes:
// 1. Development: Keys from flash (ecdsa_private_keys.h)
// 2. Production: Keys from OTP (define USE_OTP_KEYS)
// ============================================================================

// Uncomment for production builds with OTP keys:
// #define USE_OTP_KEYS

#if defined(USE_OTP_KEYS)
    // Production: Read keys from OTP at runtime
    #include "otp_keys.h"
    uint8_t ECDSA_PRIVATE_KEY[32] = {0};
    uint8_t ECDSA_PUBLIC_KEY[65] = {0};
    static bool g_otp_keys_loaded = false;
#elif __has_include("keys/ecdsa_private_keys.h")
    // Development: Keys from header file
    #include "keys/ecdsa_private_keys.h"
#else
    // Placeholder keys for development - REPLACE WITH REAL KEYS!
    #warning "Using placeholder ECDSA keys! Run generate_keys.sh to create real keys."
    static const uint8_t ECDSA_PRIVATE_KEY[32] = {0};
    static const uint8_t ECDSA_PUBLIC_KEY[65] = {0};
#endif

/* ============================================================================
 * Configuration Constants
 * ========================================================================== */

// Firmware version
#define FW_VERSION_MAJOR    6
#define FW_VERSION_MINOR    0
#define FW_VERSION_PATCH    0
#define FW_VERSION_STRING   "6.0.0"

// I2C Configuration
#define I2C_PORT            i2c0
#define I2C_SDA_PIN         8
#define I2C_SCL_PIN         9
#define I2C_BAUDRATE        400000      // 400kHz (BMP280 max spec)

// BMP280 Sensor
#define BMP280_I2C_ADDR     0x76
#define BMP280_CHIP_ID      0x58
#define BME280_CHIP_ID      0x60

// Sampling Configuration
#define INTERNAL_SAMPLE_RATE_HZ  100     // Fixed internal sampling rate
#define DEFAULT_OUTPUT_RATE_HZ   8       // Default output rate
#define MIN_OUTPUT_RATE_HZ       4       // Minimum (most stable)
#define MAX_OUTPUT_RATE_HZ       50      // Maximum (less averaging)
#define MAX_SAMPLES_PER_OUTPUT   (INTERNAL_SAMPLE_RATE_HZ / MIN_OUTPUT_RATE_HZ)  // 25 max
#define SAMPLE_INTERVAL_US       (1000000 / INTERNAL_SAMPLE_RATE_HZ)  // 10ms

// Connection Timeout
#define CONNECTION_TIMEOUT_MS   30000

// WS2812 LED (RP2350 Zero SuperMini)
#define WS2812_PIN          16
#define WS2812_IS_RGBW      false
#define LED_BRIGHTNESS      50

// Flash Storage (last 4KB sector of 4MB flash)
#define FLASH_SIZE_BYTES        (4 * 1024 * 1024)
#define FLASH_SETTINGS_OFFSET   (FLASH_SIZE_BYTES - FLASH_SECTOR_SIZE)
#define SETTINGS_MAGIC          0x44495646  // "DIVF"

// Device Settings Limits
#define DEVICE_NAME_MAX_LEN     24      // UTF-8 bytes (8 Korean chars or 24 ASCII)
#define DEVICE_PIN_LEN          4

// Inter-core Queue
#define PRESSURE_QUEUE_SIZE     32

/* ============================================================================
 * Type Definitions
 * ========================================================================== */

/**
 * @brief Flash-stored device settings structure
 * @note Must be exactly FLASH_PAGE_SIZE (256 bytes) for flash programming
 * @note CRC32 at end covers bytes 0..(size-5), using polynomial 0xEDB88320
 */
typedef struct __attribute__((packed)) {
    uint32_t magic;
    char pin[DEVICE_PIN_LEN + 1];
    char name[DEVICE_NAME_MAX_LEN + 1];
    // Runtime-configurable parameters (persisted across reboots)
    uint8_t led_brightness;      // 0-100
    uint8_t noise_floor;         // 0-50
    uint8_t oversampling_ctrl;   // 0-5
    uint8_t iir_config;          // 0-4
    uint8_t output_rate;         // 4-50 Hz
    uint8_t pin_fail_count;      // Persisted PIN failure count
    uint8_t _config_reserved[2]; // Future use
    uint8_t _reserved[FLASH_PAGE_SIZE - sizeof(uint32_t) - (DEVICE_PIN_LEN + 1) - (DEVICE_NAME_MAX_LEN + 1) - 8 - sizeof(uint32_t)];
    uint32_t crc32;              // CRC32 of bytes 0..(size-5)
} device_settings_t;

_Static_assert(sizeof(device_settings_t) == FLASH_PAGE_SIZE, 
               "device_settings_t must be exactly FLASH_PAGE_SIZE");

/**
 * @brief Pressure data packet for inter-core communication
 */
typedef struct {
    int32_t delta_x1000;  // Delta pressure in hPa * 1000
} pressure_packet_t;

/**
 * @brief BMP280 calibration data
 */
typedef struct {
    uint16_t dig_T1;
    int16_t  dig_T2, dig_T3;
    uint16_t dig_P1;
    int16_t  dig_P2, dig_P3, dig_P4, dig_P5;
    int16_t  dig_P6, dig_P7, dig_P8, dig_P9;
    int32_t  t_fine;    // Temperature for pressure compensation
} bmp280_calib_t;

/**
 * @brief LED status colors
 */
typedef enum {
    LED_STATE_OFF,
    LED_STATE_BOOT,         // Red
    LED_STATE_USB_WAIT,     // Yellow blink
    LED_STATE_USB_READY,    // Blue
    LED_STATE_APP_CONNECTED // Green
} led_state_t;

/* ============================================================================
 * BMP280 Register Definitions
 * ========================================================================== */

#define BMP280_REG_ID           0xD0
#define BMP280_REG_RESET        0xE0
#define BMP280_REG_CTRL_MEAS    0xF4
#define BMP280_REG_CONFIG       0xF5
#define BMP280_REG_PRESS_MSB    0xF7
#define BMP280_REG_CALIB_START  0x88
#define BMP280_CALIB_LEN        24

#define BMP280_RESET_VALUE      0xB6
// Stable settings: osrs_t=001 (x1), osrs_p=101 (x16), mode=11 (normal) = 0x57
#define BMP280_CTRL_STABLE      0x57    // T:x1, P:x16, normal mode
#define BMP280_CONFIG_FILTERED  0x04    // standby=0.5ms, filter=x2

// BMP280 valid measurement range (extended beyond datasheet 300-1100 hPa spec)
#define BMP280_PRESSURE_MIN_HPA     300.0f
#define BMP280_PRESSURE_MAX_HPA     1250.0f

// Over-range recovery: discard initial samples after sensor reset
// to let IIR filter stabilize with clean values
#define OVERRANGE_RECOVERY_SAMPLES  30   // ~300ms at 100Hz
#define OVERRANGE_CONSEC_THRESHOLD  10   // consecutive bad readings before reset

/* ============================================================================
 * Global State
 * ========================================================================== */

// Device identification
static char g_serial_number[PICO_UNIQUE_BOARD_ID_SIZE_BYTES * 2 + 1];
static char g_device_name[DEVICE_NAME_MAX_LEN + 1] = "DiveChecker";
static char g_device_pin[DEVICE_PIN_LEN + 1] = "0000";

// Sensor state
static bmp280_calib_t g_calib;
static volatile bool g_sensor_ready = false;

// Baseline for delta calculation
static volatile float g_baseline_pressure = 0;
static volatile bool g_baseline_set = false;
static bool g_baseline_printed = false;

// Connection state
static volatile bool g_app_connected = false;
static volatile uint64_t g_last_ping_ms = 0;

// Output rate (configurable via 'F' command)
static volatile int g_output_rate = DEFAULT_OUTPUT_RATE_HZ;
static volatile int g_output_interval_ms = 1000 / DEFAULT_OUTPUT_RATE_HZ;
static volatile int g_samples_per_output = INTERNAL_SAMPLE_RATE_HZ / DEFAULT_OUTPUT_RATE_HZ;

// Inter-core communication
static queue_t g_pressure_queue;

// LED
static PIO g_ws2812_pio = pio0;
static uint g_ws2812_sm = 0;
static bool g_led_initialized = false;

// Over-range alert flag (set by Core 1, consumed by Core 0)
static volatile bool g_overrange_alert = false;

// USB suspend state — set by tud_suspend_cb (if called)
static volatile bool g_usb_suspended = false;

/**
 * @brief Check USB bus suspended state via hardware register
 * @details tud_suspend_cb() may not fire reliably on all configurations.
 *          Reading SIE_STATUS.SUSPENDED directly from the USB controller
 *          provides a hardware-level ground truth that works regardless
 *          of whether the TinyUSB callback was invoked.
 */
static inline bool usb_is_suspended(void) {
    return g_usb_suspended ||
           ((usb_hw->sie_status & USB_SIE_STATUS_SUSPENDED_BITS) != 0);
}

// I2C grace period after multicore lockout (flash save).
// Core 1's I2C transaction may be interrupted by lockout, causing transient
// NaN readings on resume. These should not count toward over-range detection.
static volatile uint8_t g_lockout_grace = 0;
#define LOCKOUT_GRACE_SAMPLES  5  // ~50ms at 100Hz internal rate

// Runtime-configurable parameters (via SysEx) — Core 0 only
static uint8_t g_led_brightness = LED_BRIGHTNESS;    // 0-100
static volatile uint8_t g_noise_floor = 1;           // x1000 threshold (Core 1 reads)
static uint8_t g_oversampling_ctrl = 5;              // 0=skip,1=x1,2=x2,3=x4,4=x8,5=x16
static uint8_t g_iir_config = 1;                     // 0=off,1=x2,2=x4,3=x8,4=x16

// Diagnostics counters (saturating increment helper)
static inline void sat_inc_u16(volatile uint16_t *val) {
    if (*val < UINT16_MAX) (*val)++;
}

/// CRC32 (polynomial 0xEDB88320, same as zlib/PNG)
static uint32_t crc32_compute(const uint8_t *data, size_t len) {
    uint32_t crc = 0xFFFFFFFF;
    for (size_t i = 0; i < len; i++) {
        crc ^= data[i];
        for (int j = 0; j < 8; j++) {
            crc = (crc >> 1) ^ ((crc & 1) ? 0xEDB88320 : 0);
        }
    }
    return ~crc;
}

static volatile uint16_t g_sensor_error_count = 0;
static volatile uint16_t g_overrange_event_count = 0;
static volatile uint16_t g_i2c_recovery_count = 0;
static volatile int16_t g_last_temperature_x100 = 0;  // From BMP280 t_fine
static uint64_t g_boot_time_ms = 0;

// I2C cross-core protection (Core 0 commands + Core 1 sensor reads)
static mutex_t g_i2c_mutex;
static volatile bool g_sensor_reconfiguring = false;

static inline void set_sensor_reconfiguring(bool value) {
    g_sensor_reconfiguring = value;
    __dmb();  // Memory barrier for cross-core visibility
}

// PIN brute-force protection
static int g_pin_fail_count = 0;
static absolute_time_t g_pin_lockout_until;
#define PIN_MAX_FAILURES    5
#define PIN_LOCKOUT_MAX_SEC 60

// Flash write debounce: avoid excessive writes from rapid slider changes
static volatile bool g_settings_dirty = false;
static uint64_t g_settings_dirty_since_ms = 0;
#define FLASH_SAVE_DEBOUNCE_MS  3000  // Save 3s after last change

/// Mark settings as needing to be saved (debounced)
static void mark_settings_dirty(void) {
    g_settings_dirty = true;
    g_settings_dirty_since_ms = time_us_64() / 1000;
}

/* ============================================================================
 * WS2812 LED Functions
 * ========================================================================== */

static inline uint32_t rgb_to_grb(uint8_t r, uint8_t g, uint8_t b) {
    return ((uint32_t)g << 16) | ((uint32_t)r << 8) | (uint32_t)b;
}

static inline void led_set_color(uint8_t r, uint8_t g, uint8_t b) {
    if (!g_led_initialized) return;
    pio_sm_put_blocking(g_ws2812_pio, g_ws2812_sm, rgb_to_grb(r, g, b) << 8u);
}

static void led_init(void) {
    // Check PIO program space availability before adding
    if (!pio_can_add_program(g_ws2812_pio, &ws2812_program)) {
        // Try PIO1 as fallback
        g_ws2812_pio = pio1;
        if (!pio_can_add_program(g_ws2812_pio, &ws2812_program)) {
            // No PIO available — LED won't work but device continues
            return;
        }
    }
    int sm = pio_claim_unused_sm(g_ws2812_pio, false);
    if (sm < 0) return;  // No free state machine
    g_ws2812_sm = (uint)sm;
    uint offset = pio_add_program(g_ws2812_pio, &ws2812_program);
    ws2812_program_init(g_ws2812_pio, g_ws2812_sm, offset, WS2812_PIN, 800000, WS2812_IS_RGBW);
    
    // EMC: Reduce drive strength and slew rate for LED data pin
    gpio_set_drive_strength(WS2812_PIN, GPIO_DRIVE_STRENGTH_2MA);
    gpio_set_slew_rate(WS2812_PIN, GPIO_SLEW_RATE_SLOW);
    g_led_initialized = true;
}

static void led_set_state(led_state_t state) {
    uint8_t br = g_led_brightness;
    switch (state) {
        case LED_STATE_OFF:          led_set_color(0, 0, 0);                           break;
        case LED_STATE_BOOT:         led_set_color(br, 0, 0);                           break;
        case LED_STATE_USB_WAIT:     led_set_color(br * 60 / 100, br * 25 / 100, 0);    break;
        case LED_STATE_USB_READY:    led_set_color(0, 0, br);                           break;
        case LED_STATE_APP_CONNECTED:led_set_color(0, br, 0);                           break;
        default:                     led_set_color(0, 0, 0);                           break;
    }
}

// Forward declarations
static bool pin_is_valid_format(const char *pin);
static bool bmp280_apply_config(void);

// Wear leveling: use 16 slots within the 4KB sector (256 bytes each)
#define WEAR_LEVEL_SLOTS  (FLASH_SECTOR_SIZE / FLASH_PAGE_SIZE)  // 16
static int g_wear_slot = 0;  // Current active slot index

/* ============================================================================
 * Flash Storage Functions
 * ========================================================================== */

static const device_settings_t* flash_get_settings_ptr(void) {
    return (const device_settings_t*)(XIP_BASE + FLASH_SETTINGS_OFFSET);
}

/// Verify CRC32 of settings (legacy 0xFFFFFFFF accepted only if magic matches)
static bool flash_verify_crc(const device_settings_t *settings) {
    if (settings->crc32 == 0xFFFFFFFF) {
        return settings->magic == SETTINGS_MAGIC;
    }
    uint32_t computed = crc32_compute((const uint8_t*)settings, 
                                       sizeof(device_settings_t) - sizeof(uint32_t));
    return computed == settings->crc32;
}

/// Find the latest valid settings slot (wear leveling + CRC verification)
static int flash_find_active_slot(void) {
    const device_settings_t *base = flash_get_settings_ptr();
    // Scan all slots, find the last valid one (highest index)
    int active = -1;
    for (int i = 0; i < WEAR_LEVEL_SLOTS; i++) {
        if (base[i].magic == SETTINGS_MAGIC && flash_verify_crc(&base[i])) {
            active = i;
        }
    }
    return active;
}

/// Build settings struct from current global state (for flash storage)
static device_settings_t flash_build_settings(void) {
    device_settings_t s = { .magic = SETTINGS_MAGIC };
    strncpy(s.pin, g_device_pin, DEVICE_PIN_LEN);
    s.pin[DEVICE_PIN_LEN] = '\0';
    strncpy(s.name, g_device_name, DEVICE_NAME_MAX_LEN);
    s.name[DEVICE_NAME_MAX_LEN] = '\0';
    s.led_brightness = g_led_brightness;
    s.noise_floor = g_noise_floor;
    s.oversampling_ctrl = g_oversampling_ctrl;
    s.iir_config = g_iir_config;
    s.output_rate = g_output_rate;
    s.pin_fail_count = (g_pin_fail_count <= 20) ? g_pin_fail_count : 20;
    memset(s._config_reserved, 0xFF, sizeof(s._config_reserved));
    memset(s._reserved, 0xFF, sizeof(s._reserved));
    s.crc32 = crc32_compute((const uint8_t*)&s,
                             sizeof(device_settings_t) - sizeof(uint32_t));
    return s;
}
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
int main(void) {
    // =========================================================================
    // EMC: Configure unused GPIO pins to prevent floating (reduce EMI)
    // Used GPIOs: GP8 (I2C SDA), GP9 (I2C SCL), GP16 (WS2812 LED)
    // =========================================================================
    static const uint8_t used_gpios[] = {8, 9, 16};
    for (uint gpio = 0; gpio < NUM_BANK0_GPIOS; gpio++) {
        bool in_use = false;
        for (size_t i = 0; i < sizeof(used_gpios); i++) {
            if (gpio == used_gpios[i]) {
                in_use = true;
                break;
            }
        }
        if (!in_use) {
            gpio_init(gpio);
            gpio_set_dir(gpio, GPIO_IN);
            gpio_pull_down(gpio);
        }
    }
    
    init_serial_number();
    flash_load_settings();
    
    usb_set_serial_number(g_serial_number);
    tusb_init();
    
    // Initialize MIDI SysEx handler
    midi_sysex_init();
    
    // Initialize inter-core queue
    queue_init(&g_pressure_queue, sizeof(pressure_packet_t), PRESSURE_QUEUE_SIZE);
    
    // Initialize I2C mutex for cross-core access protection
    mutex_init(&g_i2c_mutex);
    
    // Initialize LED
    led_init();
    led_set_state(LED_STATE_BOOT);
    
    // Launch sensor task on Core 1
    multicore_launch_core1(core1_sensor_task);
    
    // Wait for Core 1 initialization
    uint32_t sensor_status = multicore_fifo_pop_blocking();
    g_sensor_ready = (sensor_status == 1);
    
    // Wait for USB connection with blinking LED
    // Enable watchdog early for self-recovery if USB init hangs
    watchdog_enable(8000, true);  // 8s generous timeout during boot
    uint64_t last_blink_us = 0;
    bool blink = false;
    while (!tud_connected()) {
        tud_task();
        watchdog_update();
        uint64_t now_us = time_us_64();
        if (now_us - last_blink_us > 500000) {
            last_blink_us = now_us;
            blink = !blink;
            led_set_state(blink ? LED_STATE_USB_WAIT : LED_STATE_OFF);
        }
        sleep_ms(10);
    }
    led_set_state(LED_STATE_USB_READY);
    sleep_ms(500);
    
    // Print startup info (to CDC debug port if available)
    print_startup_banner();
    
    // Record boot time for uptime calculation
    g_boot_time_ms = time_us_64() / 1000;
    
    // =========================================================================
    // EMC: Enable watchdog for auto-recovery from ESD-induced hangs
    // Timeout: 2000ms - both cores must feed regularly
    // Tighten from boot timeout (8s) to operational timeout (2s)
    // =========================================================================
    watchdog_enable(2000, true);  // 2 second timeout, pause on debug
    
    // Main loop: USB MIDI communication on Core 0
    while (true) {
        // Feed watchdog at start of each iteration
        watchdog_update();
        
        uint64_t now_ms = time_us_64() / 1000;
        
        // TinyUSB device task - MUST be called frequently
        tud_task();
        
        // Process incoming MIDI messages
        midi_task();
        
        // Check for connection timeout.
        // While USB is suspended (detected via hardware register OR
        // TinyUSB callback), pings cannot arrive — advance the ping
        // timestamp so the timeout stays paused.
        if (g_app_connected) {
            if (usb_is_suspended()) {
                g_last_ping_ms = now_ms;
            } else if (now_ms - g_last_ping_ms > CONNECTION_TIMEOUT_MS) {
                g_app_connected = false;
                g_baseline_printed = false;  // Reset for next connection
                led_set_state(LED_STATE_USB_READY);
                #if CFG_TUD_CDC
                printf("MIDI: App disconnected (timeout)\n");
                #endif
            }
        }

        // Forward pressure data from Core 1 via MIDI SysEx.
        // Data flow is decoupled from ping/pong — we send whenever
        // the USB MIDI interface is mounted.  midi_sysex_send_raw()
        // already checks tud_midi_mounted() internally.
        {
            pressure_packet_t packet;
            while (queue_try_remove(&g_pressure_queue, &packet)) {
                // Send baseline info once
                if (!g_baseline_printed && g_baseline_set) {
                    #if CFG_TUD_CDC
                    printf("INFO: Baseline %.3f hPa\n", g_baseline_pressure);
                    #endif
                    g_baseline_printed = true;
                }
                // Send pressure via MIDI SysEx
                midi_sysex_send_pressure(packet.delta_x1000);
            }

            // Send over-range alert to app (set by Core 1)
            if (g_overrange_alert) {
                g_overrange_alert = false;
                midi_sysex_send_overrange_alert();
            }
        }
        
        // Debounced flash save: write settings 3s after last change
        // Reduces flash wear from rapid slider adjustments
        if (g_settings_dirty && (now_ms - g_settings_dirty_since_ms > FLASH_SAVE_DEBOUNCE_MS)) {
            flash_save_settings();
            g_settings_dirty = false;
        }
        
        sleep_us(100);
    }
    
    return 0;
}

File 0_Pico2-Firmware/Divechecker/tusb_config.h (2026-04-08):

/**
 * @file tusb_config.h
 * @brief TinyUSB configuration for USB MIDI device
 *
 * DiveChecker RP2350 USB MIDI Configuration
 *
 * @author Createch (legal@createch.kr)
 * @copyright Copyright (C) 2025-2026 Createch
 * @license Apache License 2.0
 */

#ifndef _TUSB_CONFIG_H_
#define _TUSB_CONFIG_H_

#ifdef __cplusplus
extern "C" {
#endif

//--------------------------------------------------------------------
// COMMON CONFIGURATION
//--------------------------------------------------------------------

// Note: CFG_TUSB_MCU is auto-detected by Pico SDK via tinyusb_board
// Do NOT define it manually for RP2350 compatibility
#define CFG_TUSB_OS                 OPT_OS_PICO
#define CFG_TUSB_DEBUG              0

// Enable device stack
#define CFG_TUD_ENABLED             1

// RHPort number used for device
#define BOARD_TUD_RHPORT            0

// RHPort max operational speed
#define BOARD_TUD_MAX_SPEED         OPT_MODE_FULL_SPEED

// RHPort mode (required by TinyUSB)
#define CFG_TUSB_RHPORT0_MODE       (OPT_MODE_DEVICE | OPT_MODE_FULL_SPEED)

//--------------------------------------------------------------------
// DEVICE CONFIGURATION
//--------------------------------------------------------------------

#define CFG_TUD_ENDPOINT0_SIZE      64

//------------- CLASS CONFIGURATION -------------//

// MIDI Class
#define CFG_TUD_MIDI                1
#define CFG_TUD_MIDI_RX_BUFSIZE     64
#define CFG_TUD_MIDI_TX_BUFSIZE     512

// CDC Class (debug output) - disabled by default for clean USB MIDI.
// Enable with: target_compile_definitions(... PRIVATE DEBUG_CDC=1)
// When enabled, adds a CDC serial port for printf debug output.
// WARNING: Leaving CDC active in production causes periodic ~0.5s data
// dropouts due to Linux cdc-acm driver polling and USB bandwidth contention.
#ifdef DEBUG_CDC
#define CFG_TUD_CDC                 1
#define CFG_TUD_CDC_RX_BUFSIZE      256
#define CFG_TUD_CDC_TX_BUFSIZE      256
#else
#define CFG_TUD_CDC                 0
#endif

// Disable unused classes
#define CFG_TUD_MSC                 0
#define CFG_TUD_HID                 0
#define CFG_TUD_VENDOR              0

#ifdef __cplusplus
}
#endif

#endif /* _TUSB_CONFIG_H_ */

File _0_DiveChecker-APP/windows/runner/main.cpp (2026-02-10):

#include <flutter/dart_project.h>
#include <flutter/flutter_view_controller.h>
#include <windows.h>

#include "flutter_window.h"
#include "utils.h"

int APIENTRY wWinMain(_In_ HINSTANCE instance, _In_opt_ HINSTANCE prev,
                      _In_ wchar_t *command_line, _In_ int show_command) {
  // Attach to console when present (e.g., 'flutter run') or create a
  // new console when running with a debugger.
  if (!::AttachConsole(ATTACH_PARENT_PROCESS) && ::IsDebuggerPresent()) {
    CreateAndAttachConsole();
  }

  // Initialize COM, so that it is available for use in the library and/or
  // plugins.
  ::CoInitializeEx(nullptr, COINIT_APARTMENTTHREADED);

  flutter::DartProject project(L"data");

  std::vector<std::string> command_line_arguments =
      GetCommandLineArguments();

  project.set_dart_entrypoint_arguments(std::move(command_line_arguments));

  FlutterWindow window(project);
  Win32Window::Point origin(10, 10);
  Win32Window::Size size(1280, 720);
  if (!window.Create(L"DiveChecker", origin, size)) {
    return EXIT_FAILURE;
  }
  window.SetQuitOnClose(true);

  ::MSG msg;
  while (::GetMessage(&msg, nullptr, 0, 0)) {
    ::TranslateMessage(&msg);
    ::DispatchMessage(&msg);
  }

  ::CoUninitialize();
  return EXIT_SUCCESS;
}

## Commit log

2026-01-15 [release] alpha release 0.1.1
    [BME280-5V-raw.FCStd, BME280-5V.FCStd, Device_V4-몸통.stl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]
2026-01-22 [release] alpha release 0.3.0
    [Device_V4.FCStd]
2026-01-30 [release] release 1.1.0
    [Device_V4-몸통004.stl, Device_V4.FCStd, Device_V4_0.FCStd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]
2026-01-30 ci: android build
    [Device_V4-몸통.stl, Device_V4-몸통002.stl, Device_V4-몸통003.stl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]
2026-02-10 [release] release 2.0.0
    [BME280-5V-raw-BME280-5V.step, BME280-5V-raw.FCStd, Device_V4-몸통004.stl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]
2026-02-12 [release] release 2.1.0 old firnware support latest version
    [Device_V8-Main-body.stl]
2026-02-19 [release] release 2.2.0
    [Device_V9-Core-sub.stl, Device_V9-Main-body.stl]
2026-02-24 [release] release 4.0.0 (RTM)
    [Device_V10-Main-body.stl]
2026-02-26 fix: stabilize firmware sampling and reconnect behavior
    Decouple Core 1 sensor sampling from app connection state and harden flash/I2C recovery paths to remove transient dropouts, spikes, and baseline reset artifacts during reconnect and settings persistence.
    Made-with: Cursor
    [Divechecker.c, midi_sysex.c]
2026-02-26 refactor: migrate app stack to MIDI-first flow and improve runtime stability
    Remove legacy serial compatibility paths, rename device selection flow, harden monitor/measurement update pipelines, and align app tests and persistence updates with the new MIDI-based architecture.
    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
2026-02-26 docs: refresh release docs and multi-platform build metadata
    Update root/CAD documentation and CI release workflow details to match current platform packaging, version line, and project structure naming.
    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
2026-02-27 fix: add missing __dmb() barriers for cross-core memory ordering in firmware
    Add Data Memory Barriers to three locations where cross-core variable
    visibility was not guaranteed on RP2350 dual Cortex-M33:
    - CMD_RESET_BASELINE: ensure Core 1 sees g_baseline_set=false immediately
    - Core 1 baseline init: ensure g_baseline_pressure is visible before
    g_baseline_set is set to true (prevents Core 0 seeing stale pressure)
    - flash_save_settings: ensure g_lockout_grace is written after lockout
    ends, consistent with existing __dmb() usage in CMD_SET_OUTPUT_RATE
    [Divechecker.c]
2026-03-08 fix: decouple pressure data flow from ping/pong connection state
    Periodic ~0.5s data dropouts occurred because app pong timeout (8s)
    triggered disconnect → pings stopped → firmware CONNECTION_TIMEOUT
    fired → g_app_connected=false → data flow halted → LED blue.
    Now data flow is gated solely on tud_midi_mounted() (USB level),
    not on g_app_connected (application level). Core 1 always queues
    pressure data, Core 0 always drains and sends via MIDI SysEx.
    g_app_connected only controls LED state. Also adds USB suspend
    detection via SIE hardware register and increases connection
    timeout from 10s to 30s as a safety margin.
    [Divechecker.c, midi_sysex.c, tusb_config.h]
2026-03-10 feat: add fullscreen chart view for real-time measurement
    Add a fullscreen landscape mode to the measurement screen's pressure
    chart. Includes compact stats overlay (current pressure, peak, average),
    recording indicator with elapsed time, and immersive UI with hidden
    system bars. Bump build number to 2 for App Store re-upload.
2026-03-10 feat: add fullscreen chart view for real-time measurement
    chart with compact stats overlay, recording indicator, and immersive
    UI. Bump app version to 7.0.3.
    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
2026-03-11 feat: add session delete button to history screen
    Add delete icon button on each session card with confirmation dialog.
    Backend delete logic and localization strings were already implemented.
    Bump app version to 7.0.4.
2026-03-18 fix: 출시 전 코드 품질 개선
    - [App] 3개 컴파일 에러 수정 (midi_provider, ecdsa_utils, backup_service)
    - [App] 277개 withOpacity deprecation 수정 → withValues(alpha:)
    - [Docs] LICENSE 경로, CHANGELOG 날짜, README 언어 목록 수정
    - [Website] contact form mailto 방식, i18n 언어수, nav data-i18n 추가
    - [CI/CD] RunnerTests bundle ID 수정, test job 추가
    - [Ref] AI_REFERENCE.md 세션 상태 문서화
    flutter analyze: 0 errors, 0 warnings
    flutter test: All tests passed
    [Divechecker.c]
2026-03-18 fix: update README sampling rate to 160Hz and fix CONTRIBUTING links
    Update architecture version v6.0.0 → v7.2.0, sampling rate 100Hz → 160Hz
    across both README.md and README.ko.md. Fix CONTRIBUTING.md links to
    point to root instead of app subdirectory.
2026-03-18 fix: update sampling rate 100Hz → 160Hz in firmware and app READMEs
2026-03-18 fix: remove device serial registry from git tracking
    divechecker_serials.csv contains real device serial numbers
    and should not be in version control. Added to .gitignore.
2026-03-18 fix: reset MIDI data listener on device switch to prevent staircase graph
    When switching between USB MIDI devices, the native data subscription
    was not reset, causing OS-level buffered packets to flush in a burst
    on reconnection. Now disconnect cancels the listener and connect
    re-establishes it fresh. Also ensures previous device is properly
    disconnected before connecting a new one.
    Version bump to 8.0.1+2.
2026-03-19 feat: RTM 8.1.0 — macOS ASC upload, stability hardening, docs alignment
    macOS ASC upload & app hardening:
    - Add macOS App Store Connect auto-upload to CI/CD pipeline
    - Add macOS ExportOptions.plist for signed distribution
    - Optimize chart rendering with single-pass min/max calculation
    - Add mounted check and error handling in graph notes loading
    - Replace Consumer with Selector in measurement screen
    - Add StreamController cleanup in MidiProvider shutdown
    - Harden .gitignore: add .p12, .p8, .env, provisioning profile rules
    - Remove tmp-igbkp/ from git tracking
    Align all docs and app constants with firmware source of truth:
    - Sampling rate: 160Hz → 100Hz (matches INTERNAL_SAMPLE_RATE_HZ)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
2026-03-20 feat: RTM 8.2.0 — consolidate all certs/keys into .certs/
    - Android keystore/key.properties → .certs/android/ (CI + local)
    - ECDSA device auth keys → .certs/ecdsa/ (symlink from firmware/keys/)
    - Secure boot keys → .certs/secure_boot/
    - macOS CI: shared Apple Distribution cert + separate Installer cert
    - build.gradle.kts: dual key.properties lookup (.certs/ → CI fallback)
    - Removed redundant firmware root ecdsa_private_keys.h
    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
2026-03-20 fix: RTM 8.3.0 — fix staircase graph on device switch (subscription leak)
    LinuxMidiDevice.connect() subscribed to receivedMessages without storing
    or cancelling the StreamSubscription. On device A→B switch, the same
    AlsaMidiDevice was reused (cached _allAlsaDevices), accumulating duplicate
    subscriptions. Each MIDI packet was delivered N times, producing repeated
    Y-values at consecutive X positions — the staircase pattern.
    Fixes:
    - Store and cancel StreamSubscription in LinuxMidiDevice connect/disconnect
    - Re-enumerate ALSA devices on every scan to detect USB hot-plug changes
    - Lock output rate at measurement start to prevent X-axis drift
    - Clear data buffers on device change in Monito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
2026-03-20 fix: RTM 8.3.2 — CI test fix + MonitorScreen dispose safety
    CI test failed on ubuntu: sqflite databaseFactory not initialized.
    MonitorScreen.dispose() crashed accessing deactivated widget context.
    - Initialize sqflite FFI in test setUpAll for headless CI environment
    - Use pump() instead of pumpAndSettle() (app has persistent timers)
    - Cache MidiProvider reference in MonitorScreen to avoid context.read
    in dispose() which crashes on deactivated widget tree
    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
2026-03-26 fix: RTM 8.3.2-80302 bump versionCode and relax USB host requirement for Play Store compatibility
    - Change versionCode from 1 to 80302 (major×10000+minor×100+patch)
    - Set android.hardware.usb.host required=false to maintain device compatibility with previous release
2026-04-01 feat: keep screen on during measurement and monitoring
    Add wakelock_plus to prevent auto screen-off while actively
    measuring or monitoring pressure data.
2026-04-07 chore: rebrand to Createch (크리에이테크) and bump version to 8.5.0
    - Update all copyright headers, LICENSE, and README files to Createch (legal@createch.kr)
    - Migrate contact emails to createch.kr domain (legal@, contact@, cs-divechecker@, info@)
    - Update privacy policies with Createch branding and cs-divechecker@ contact
    - Update website footers, KC certification info (R-R-DCQ-DC), and product name to 디지털 압력 감지 학습기
    - Change USB manufacturer string from kodenet.io to createch.kr
    - Change Linux APPLICATION_ID to kr.createch.divechecker
    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
2026-04-07 fix: correct FAQ translations and remove duplicate i18n keys
    - Fix faq.q2~q17 ja/zh/tw translations (were shuffled with wrong Q&A pairs)
    - Translate faq entries that had English-only ja/zh/tw placeholders
    - Fix Traditional Chinese character errors (吗→嗎, 天气→天氣, etc.)
    - Remove duplicate footer.disclaimer and support.form-subject-ph keys
2026-04-07 fix: correct faq.a7 — Lightning is supported with camera adapter
2026-04-07 fix: correct brand name order, fix broken guide.html links, add footer tagline
    - Fix brand name: Createch(크리에이테크) → 크리에이테크 (Createch)
    - Fix broken guide.html links → index.html#manual (guide.html doesn't exist)
    - Add data-i18n to Bluetooth table header
    - Add footer tagline below logo on all pages with full footer
2026-04-09 fix: add sensor init timeout to prevent USB hang when BMP280 is disconnected
    [Divechecker.c]
2026-04-28 feat(website): default to English with browser-locale fallback
    Switch the site default language to English so foreign-first visitors
    land on English copy without an interaction. Korean (and other supported
    locales) are still chosen automatically when the browser advertises them.
    - i18n: add browser-locale detection, default fallback en (was ko)
    - i18n: always run applyTranslations on load so HTML defaults are replaced
    - i18n: missing-key fallback now ko -> en -> ko
    - i18n: add footer.copyright key (drops "크리에이테크" prefix outside ko)
    - html: lang="ko" -> lang="en" across all 5 pages
    - index: default <title> in English
    - privacy: load English policy and toggle order English-first;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
2026-04-28 fix(website): force English as default, drop browser-locale auto-switch
    Korean-locale browsers were being auto-flipped to ko on first visit,
    which contradicts the foreign-first intent. Default to en unconditionally;
    explicit user choice via the toggle is still persisted in localStorage.
2026-05-01 feat(website): add DiveChecker Vent product page + Products nav dropdown
    - vent.html: full product landing page (hero, problem, solution, 4 features,
    3-step how-it-works, comparison vs generic balloon, do→measure→fix bundle
    loop, specs, package, coming-soon CTA, trust, footer)
    - nav: Products dropdown listing DiveChecker (sensor) and DiveChecker Vent;
    applied across index/faq/support/disclaimer/privacy with active markers
    - mobile menu: products grouped block; existing script.js auto-handles links
    - i18n: ~85 new keys (nav.products.*, vent.*) in en/ko/ja/zh/tw
    - style.css: dropdown, mobile-products-group, feature-icon-card,
    bundle-loop, cta-coming styles + responsive breakpoints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
2026-05-02 refactor(website): naturalize Korean copy across i18n.js
    Korean strings read like literal English translation rather than native
    marketing copy. Rewrite ~128 ko entries to:
    - Drop noun-stub endings ("수강료만 날리는 악순환." → "...빠져나가는 악순환")
    - Replace anglicism ("디바이스" → "장비", "리스크" → "위험")
    - Soften over-formal tone ("...획득한 제품입니다" → "...받은 제품이에요")
    - Fix awkward sentence patterns directly translated from English
    - Vent page especially — redo the entire page copy
    Only ko values changed; en/ja/zh/tw untouched. Default-en HTML unchanged.
2026-05-02 refactor(website): rewrite Vent page Korean as native KR marketing copy
    Previous Vent page Korean still read as English-translated:
    - "X = Y" formulations ("풍선 크기 = 시각 피드백")
    - Direct calques ("근육을 가르치다", "짝을 이루다", "닫힌 학습 루프")
    - Awkward verb choices ("이퀄라이징을 트는", "압력 주기")
    - "Why X, not Y" sentence patterns ("왜 그냥 풍선이 아니라 교정된 풍선일까")
    - Over-formal endings ("사용을 금합니다", "추측에 의존하게 돼요")
    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
2026-05-02 refactor(website): reposition Vent as a Mouthfill-specific trainer
    The Vent isn't a generic equalization device — it's a dry-land Mouthfill
    practice tool. Otovent's design repurposed for the specific freediving
    need: simulating depth resistance to drill the Mouthfill compression
    posture before going deep.
    Repositioning across all 5 langs (en/ko/ja/zh/tw):
    - Hero: "Master your Mouthfill without water"
    - Page title: "Dry-Land Mouthfill Trainer"
    - Hero badge: "Mouthfill Dry Trainer"
    - Hero CTA: "Get Notified" (was "Buy Now" — coming-soon mismatch)
    - Problem: refocus on the depth-only-matters / first-time-on-real-dive risks
    - Solution: balloon's back-pressure stands in for depth
    - Features: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
2026-05-05 fix(website): correct Mouthfill technique details on Vent page
    Previous copy described "Mouthfill compression" loosely as "tongue +
    larynx squeeze" and confused it with general Frenzel. Mouthfill is a
    specific deep-dive technique with three distinct motions:
    1. Charge — take air into the mouth at the charging depth (~25-30m,
    where lung Frenzel stops working)
    2. T-block — close off the throat to seal mouth air from the lungs
    3. Tongue piston — push the mouth-stored air through the nasal
    passage with tongue + soft palate
    The Vent's value is that the calibrated balloon can ONLY be inflated
    by this charge→T-block→tongue-piston sequence. Valsalva won't do it,
    nor will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
2026-05-05 polish(website): finalize Vent page after Mouthfill accuracy pass
    After landing accurate Mouthfill terminology, a few details still felt
    off relative to the new vocabulary:
    - specs.balloon-pres-val: drop the made-up "16 kPa (120 mmHg)" — that
    number was speculative; defer the exact threshold to launch
    - specs.balloon-life-val: 100 → 50–100 (more conservative, hedges the
    Otovent-class life claim)
    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
2026-05-08 feat(website): add Vent FAQ category + align balloon-life spec
    FAQ:
    Add a "DiveChecker Vent" category (cat5) with four conceptual questions:
    - Q20: What is Vent, and how is it different from the sensor?
    - Q21: When should I start using Vent?
    - Q22: Can Vent work without the sensor?
    - Q23: How is it different from regular Otovent?
    The answers reinforce the Mouthfill positioning (charge → T-block →
    tongue piston, ~25-30m depth where lung Frenzel fails) and clarify the
    relationship between Vent, the DiveChecker sensor, and generic Otovent.
    Specs alignment:
    Hero says "100+ cycles" but specs said "~50-100 cycles" — inconsistent.
    Settle on "~100 cycles" / "약 100 사이클" in both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
2026-05-10 feat(website): add Vent closing finale + polish FAQ Korean tone
    Closing finale:
    Vent page lacked the emotional cap that index has. Add a closing
    section between Trust and Footer mirroring the index pattern:
    "It's not that you can't.
    You just had nowhere to drill it."
    5 langs (en/ko/ja/zh/tw) — natural KR tone, parallel structure to the
    existing closing.title on index ("It's not that you can't Frenzel.
    You just had no way to see it.").
    FAQ Korean polish:
    - a20: "배움이 완성됩니다" → "학습이 완성돼요" (less literary)
    "강제로 가르치는" → "직접 가르쳐주는" (less harsh)
    - a22: "권장드립니다" → "권장합니다" (correct honorific form)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
2026-05-11 feat(website): add Open Graph + Twitter Card meta + JSON-LD Product schema
    Until now, sharing any DiveChecker URL on Slack/Discord/Twitter/Facebook
    showed a blank link preview (no image, no title block). Google also had
    no Product rich-result data for our pages.
    Across all 6 HTML pages, add:
    - Open Graph meta block (og:type, og:url, og:title, og:description,
    og:image, og:locale + alternates for ko/ja/zh/tw)
    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
2026-05-11 feat(website): robots.txt + sitemap.xml + canonical URLs for SEO
    Without these, Google has to discover pages by following links and has
    no signal about which language variants belong together. Add:
    - robots.txt — allow all + point to sitemap
    - sitemap.xml — 6 URLs with priorities (1.0 root, 0.9 vent, 0.7 faq/
    support, 0.3 legal) and full hreflang alternates per page covering
    en/ko/ja/zh/zh-TW + x-default
    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
2026-05-20 docs(readme): Star History chart + Contributors graph + activity badges
    Match winpodx pattern: insert visual repo-health blocks before the
    Sponsor section in both EN and KO READMEs.
    - ## Star History — embeds api.star-history.com SVG chart with
    prefers-color-scheme branching (dark/light variants)
    - ## Contributors & Activity — contrib.rocks avatar mosaic + five
    shields.io stat badges: commit-activity/m, last-commit, issues,
    open PRs, repo-size
    - Sponsor section: upgraded from a markdown table to three big
    for-the-badge buttons (Ko-fi, Fairy, GitHub Sponsor) so it matches
    winpodx's visual hierarchy
2026-05-21 fix(app): register flutter_midi_command Windows backend ("정품인증 실패")
    Root cause of the Windows-only "정품인증 실패" (genuine-device auth
    failure) error: the Windows Flutter build had no MIDI backend
    registered, so `_midiHandler.sendSysEx()` silently no-op'd. The ECDSA
    auth challenge nonce never left the host, the device never sent an
    AUTH_RESPONSE, and the 3-second timeout in `_authenticateDevice()`
    flipped `_isAuthenticated = false`.
    Evidence:
    - `windows/flutter/generated_plugins.cmake` listed only
    `permission_handler_windows` and `universal_ble` — no MIDI plugin.
    - `linux/flutter/generated_plugins.cmake` includes
    `flutter_midi_command_linux`, and macOS's GeneratedPl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
2026-05-21 chore(release): bump to 8.6.1 — Windows MIDI plugin registration fix
    Patch release covering the Windows-only "정품인증 실패" auth failure
    landed in 8f29d6f. App version 8.6.0+80600 → 8.6.1+80601 (Android
    build number bumped accordingly). CHANGELOG.md + docs/CHANGELOG.ko.md
    get a Highlights block + Fixed entry under [8.6.1] - 2026-05-21.
    Triggers .github/workflows/build.yml on `v*` tag push: Android (apk/aab),
    iOS, macOS, Windows, Linux, Web → uploaded to GitHub Releases + App
    Store Connect on macOS.
2026-05-21 ci(ios): pin macos-15 + select Xcode 26 (latest-stable)
    App Store Connect now rejects IPAs built with anything older than the
    iOS 26 SDK:
    "SDK version issue. This app was built with the iOS 18.5 SDK.
    All iOS and iPadOS apps must be built with the iOS 26 SDK or
    later, included in Xcode 26 or later, in order to be uploaded
    to App Store Connect or submitted for distribution."
    The v8.6.1 tag run failed with this on the upload step.
    build-ios and build-macos jobs:
    - runs-on: macos-latest → macos-15 (locked image with newer Xcode)
    - add maxim-lobanov/setup-xcode@v1 with xcode-version: latest-stable
    so the runner uses the newest installed Xcode (26.x) instead of
    the default-sele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
2026-05-21 ci(release): use CHANGELOG.md section as GitHub release body
    Previous release notes were a one-line "Full Changelog: compare URL"
    stub from softprops/action-gh-release's auto-generator. The repo
    doesn't squash PRs into the main flow, so the auto-generator had
    nothing meaningful to surface.
    Add an "Extract release notes from CHANGELOG" step that awk-slices
    the matching `## [X.Y.Z]` block out of CHANGELOG.md and writes it to
    RELEASE_BODY.md, then feeds that to softprops via body_path. Append
    a Downloads table (Android apk/aab, iOS ipa, macOS, Windows, Linux,
    Web) + a pointer to SHA256SUMS.txt + a compare-URL footer so the
    release page is self-contained without forcing readers to click into
    CH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
